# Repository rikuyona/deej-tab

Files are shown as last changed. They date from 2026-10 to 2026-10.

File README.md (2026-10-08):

# deej-tab

物理スライダーで、Windows / Mac のアプリごとの音量と **Chrome のタブごとの音量** を操作する自作ミキサーです。
[deej](https://github.com/omriharel/deej) を元に、PC アプリ・Chrome 拡張機能・LED 付きファームウェア・3D プリント用ケース（[MakerWorld](https://makerworld.com/models/3382344)）までまとめてあります。

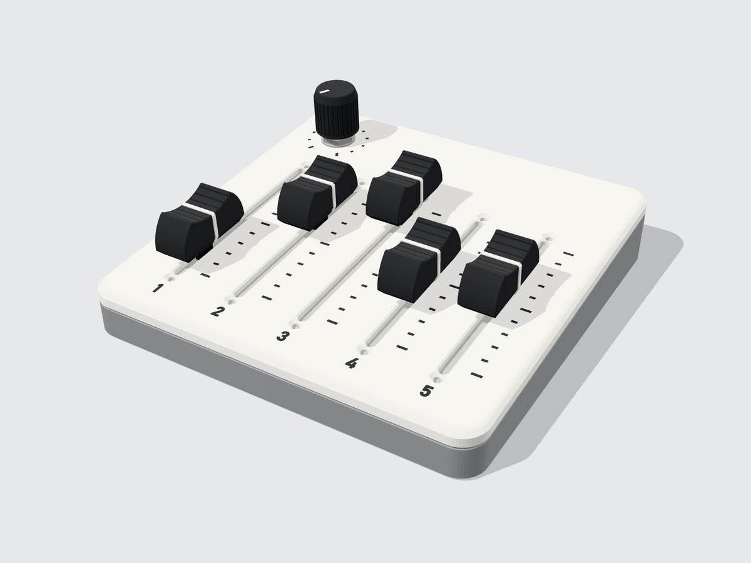
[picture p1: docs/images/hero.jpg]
deej-tab の完成イメージ

<p align="center"><sub>完成イメージ（3D レンダリング）。スライダー 5 本・ノブ 1 つ、外形 126×126mm</sub></p>

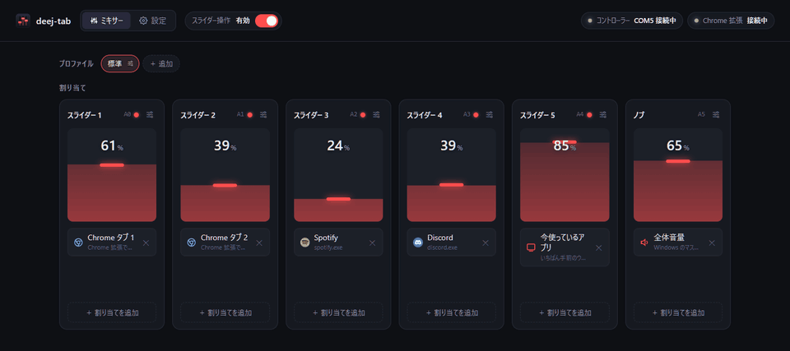
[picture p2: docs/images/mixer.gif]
設定画面：スライダーを動かすと、割り当てた音量がリアルタイムに変わる


- [できること](#できること) / [必要なもの](#必要なもの) / [セットアップ](#セットアップ) / [使い方](#使い方) / [Mac 版について](#mac-版について) / [仕組み](#仕組み) / [開発](#開発)

## できること

- スライダー 5 本＋ノブ 1 つに、全体音量・マイク・アプリ（Discord・Spotify など）・**Chrome のタブ**・今使っているアプリ・ゲーム・OBS の音声ソースを割り当てる
- Chrome で開いた配信や動画を、タブごとに別のスライダーで調整（Alt+Shift+A でタブを割り当て）
- 日本語・英語の画面（English UI）
- 設定画面で割り当て・スライダーごとの最大音量（100% 超えも可。タブ・OBS のみ）・音量の変わり方を変更
- プロファイル（割り当て一式）の切り替え。アプリが前に来たら自動で切り替えも可
- 一時停止（ショートカットも可）。止めるとアプリの音量を元に戻す（全体の音量はそのまま）
- スライダーの LED で状態や音の大きさを表示。光り方は設定画面で選べる
- config.yaml は deej と互換

## 必要なもの

### PC

- Windows 10 / 11、または macOS 14.2 以降の Apple シリコン（M1 以降）の Mac（Mac は [Mac 版について](#mac-版について) を参照）
- Google Chrome 116 以降（タブの音量を操作する場合）

### 部品

| 部品 | 例 | 数 |
|---|---|---|
| マイコン | Arduino Nano 互換ボード（USB Type-C 版。ケースは Mini-USB の Nano には合いません） | 1 |
| スライダー | Bourns PTL60-15R0-103B2（60mm・10kΩ B カーブ・赤 LED 付き） | 5 |
| 回転ボリューム | 16mm 型 10kΩ B カーブ（SH16K4B103L20KCCI など。6mm ローレット軸 18 山・軸長 20mm・M7 取付ネジ・回り止め付き） | 1 |
| ノブ | 3D プリント（[MakerWorld](https://makerworld.com/models/3382344) のデータ）または市販の 6mm 軸用（ABS-28 など） | 1 |
| LED 用抵抗 | 180Ω〜1kΩ（1/4W・1/6W など。例：330Ω） | 5 |
| M2 皿ネジ | M2×4 程度（ケースにスライダーを固定。1 本につき 2 本） | 10 |

LED 用抵抗：スライダーの赤色 LED はデータシートで順方向電流 20mA・順方向電圧 1.8V（標準）と規定されているので、5V で 20mA 以下にするには (5V − 1.8V) ÷ 20mA ≒ 160Ω 以上が必要です。値が小さいほど明るくなります（330Ω で約 10mA）。

LED なしのスライダーでも動きます（LED の機能が使えないだけです）。

### 配線

配線図

同じ名前の札どうしをつなぎます。5V と GND は全部の部品で共通なので、まとめて Nano の 5V・GND へつなぎます。

| 部品 | 端子 | つなぐ先 |
|---|---|---|
| スライダー 1〜5 | 1 | GND |
| | 3 | 5V |
| | 2（ワイパー） | A0〜A4 |
| | B（LED＋） | 抵抗 → D3 / D5 / D6 / D9 / D10 |
| | E（LED−） | GND |
| | L | つながない |
| 回転ボリューム | 両端 | 5V / GND |
| | 中央 | A5 |

D0 / D1 は USB シリアルに使うので空けておきます。

**基板版**：スライダー 5 本とノブを 1 枚の基板に載せ、Nano とはケーブル 3 本でつなぐ版も用意しています。配線が楽になります。基板を発注・組み立てて、6ch の値と LED が動くことを確かめてあります。ガーバーは [Releases](../../releases) の `pcb-v0.1.0`、部品・組み立て・注文のしかたは [pcb/README.md](pcb/README.md) にあります。

## セットアップ

[Releases](../../releases) から最新版の zip をダウンロードします。

### 1. ファームウェアを書き込む

1. `deej-tab-firmware-x.y.z.zip` を展開する
2. [Arduino IDE](https://www.arduino.cc/en/software) で `firmware/deej-6ch-led/deej-6ch-led.ino` を開く
3. ボード「Arduino Nano」、ポートを選んで書き込む
   - 互換品で失敗する場合は、プロセッサを「ATmega328P (Old Bootloader)」にする
   - ポートが出ない場合は CH340 のドライバを入れる
   - deej-tab が起動中だと書き込めません（トレイから終了してから）

### 2. PC アプリを入れる

1. `deej-tab-x.y.z-windows.zip` を展開し、好きな場所に置く（設定ファイルとログは exe の隣に作られます）
2. `deej-tab.exe` を起動する
   - 署名していないため「Windows によって PC が保護されました」と出ることがあります。「詳細情報」→「実行」で起動できます
3. タスクトレイのアイコンをクリックすると設定画面が開きます。「設定」→「コントローラー」でマイコンの COM ポートを選びます

Mac の場合は [Mac 版について](#mac-版について) を見てください。

### 3. Chrome 拡張機能を入れる

1. `deej-tab-extension-x.y.z.zip` を展開する（展開したフォルダは消さずに残しておく）
2. Chrome で `chrome://extensions` を開き、右上の「デベロッパー モード」をオンにする
3. 「パッケージ化されていない拡張機能を読み込む」で、展開した `deej-tab-extension` フォルダを選ぶ

更新するときは、新しい版でフォルダの中身を置き換えて、`chrome://extensions` の「更新」ボタン（↻）を押します。

### 4. ケースを印刷する（任意）

ケース・ツマミの 3D データは MakerWorld で配布しています。印刷設定と組み立て方もそちらにあります。

| 分解図 | スライダーのツマミ | 上から |
|---|---|---|
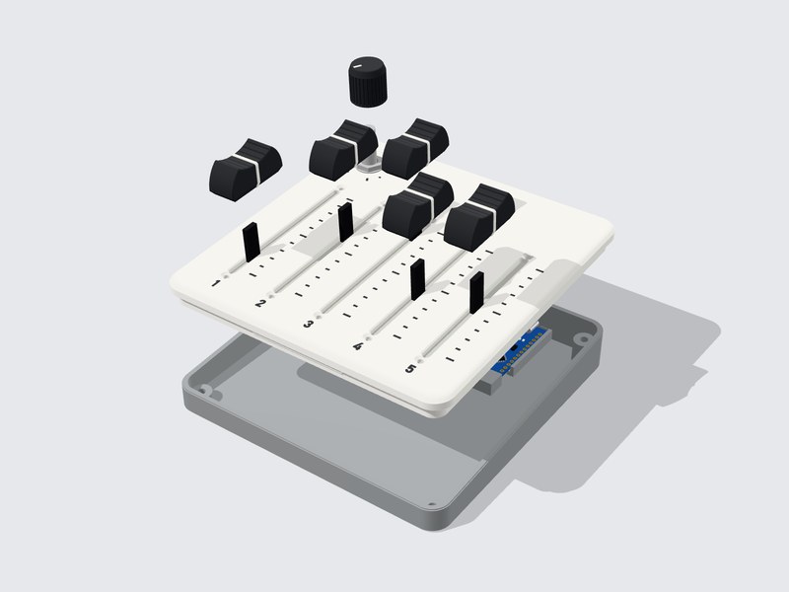
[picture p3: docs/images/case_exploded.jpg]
分解図
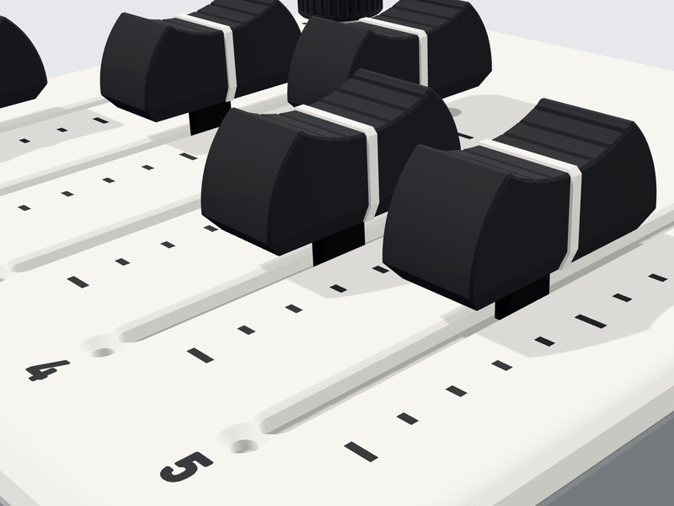
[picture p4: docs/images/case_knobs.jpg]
スライダーのツマミ
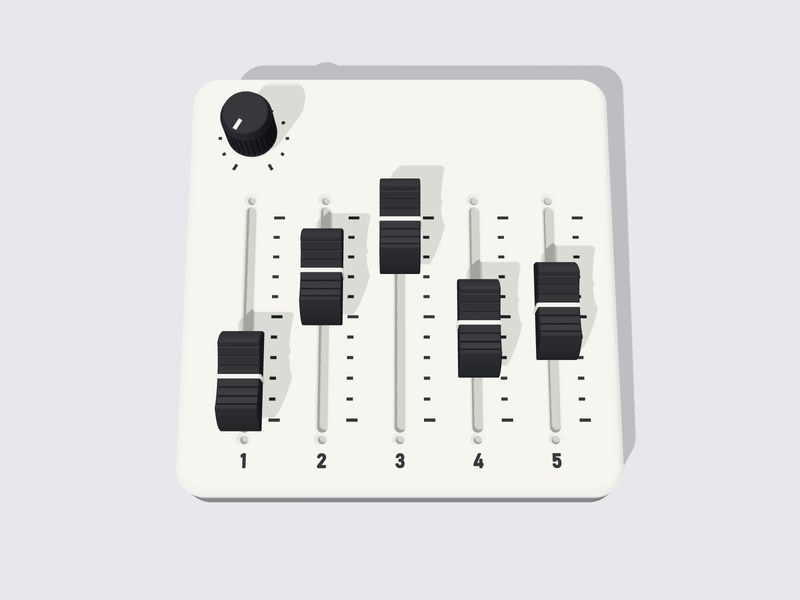
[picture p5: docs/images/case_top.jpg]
上から
|  |  |  |
| 天板・底ケース・Arduino Nano 固定クリップの 3 部品＋ツマミ | 黒い外殻と白い芯の 2 色。LED の光で白い線が光ります | 目盛りと番号は彫り。塗料を流し込んで色を付けます |

**MakerWorld：** [deej-tab Volume Mixer (5 faders + knob, LED)](https://makerworld.com/models/3382344)

寸法を変えたいときは `case/case.py` の先頭の設定を書き換えて作り直せます（[開発ガイド](docs/dev/README.md#ケースを作る)）。

## 使い方

deej-tab はタスクトレイに常駐します。アイコンをクリックすると設定画面が開きます。右クリックのメニューからは、一時停止・プロファイルの切り替え・自動起動のオン／オフ・終了ができます。

### ミキサー：スライダーに割り当てる

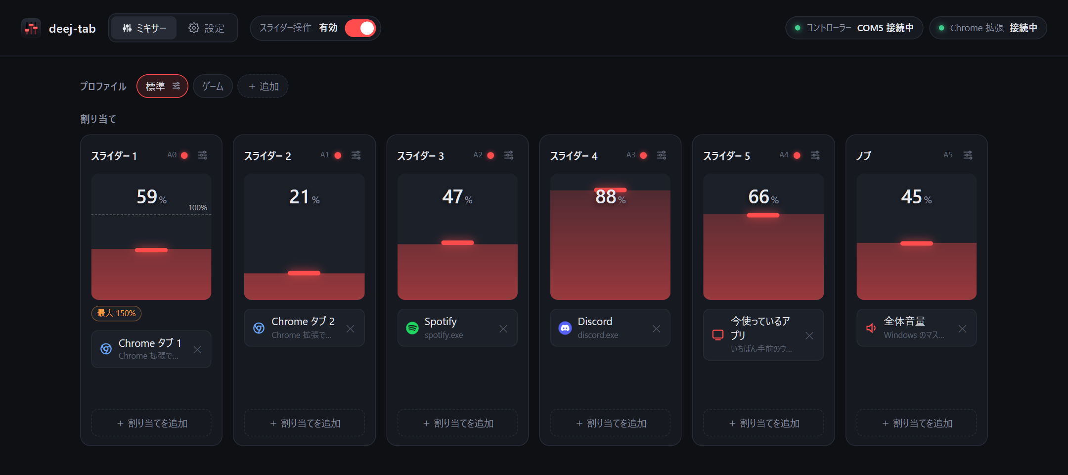
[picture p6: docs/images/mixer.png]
ミキサー


スライダー 1〜5 とノブのそれぞれに、操作したい音量を割り当てます。各スライダーの「＋ 割り当てを追加」から選び、1 本に複数を割り当てることもできます。メーターの塗りが今の音量、赤いつまみがスライダーの位置です。

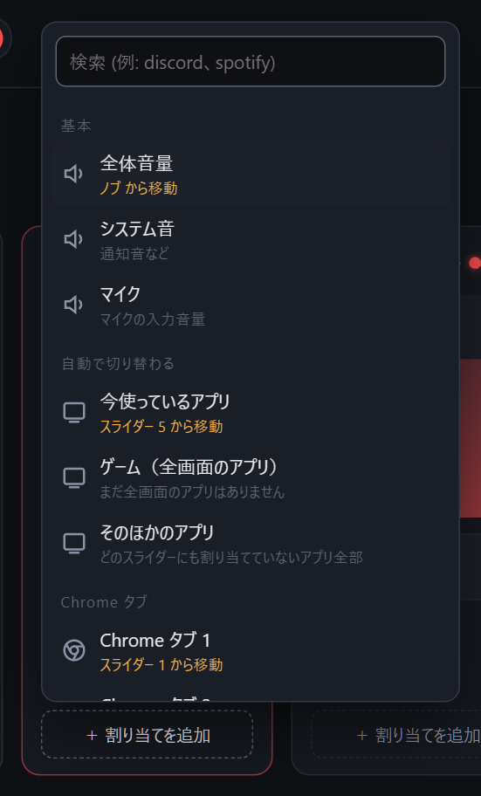
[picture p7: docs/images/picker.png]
割り当ての追加


選べるもの：

| 種類 | 内容 |
|---|---|
| 全体音量・システム音・マイク | Windows の音量 |
| 今使っているアプリ | いちばん手前のウィンドウのアプリ（ゲーム中ならゲーム） |
| ゲーム（全画面のアプリ） | 最後に全画面だったアプリ。ほかのウィンドウが前に来ても操作し続けます |
| そのほかのアプリ | どのスライダーにも割り当てていないアプリ全部 |
| Chrome タブ 1〜6 | 拡張機能で番号を付けたタブ（[下](#chrome-のタブの音量を操作する)） |
| アプリ | 音を出しているアプリ・起動中のアプリ・インストール済みのアプリから選べます。検索もできます |
| OBS の音声ソース | OBS 連携をオンにすると出ます |

同じ割り当て先は 1 本のスライダーにしか置けません（ほかのスライダーにあれば移動します）。

<br clear="right">

### スライダーごとの設定

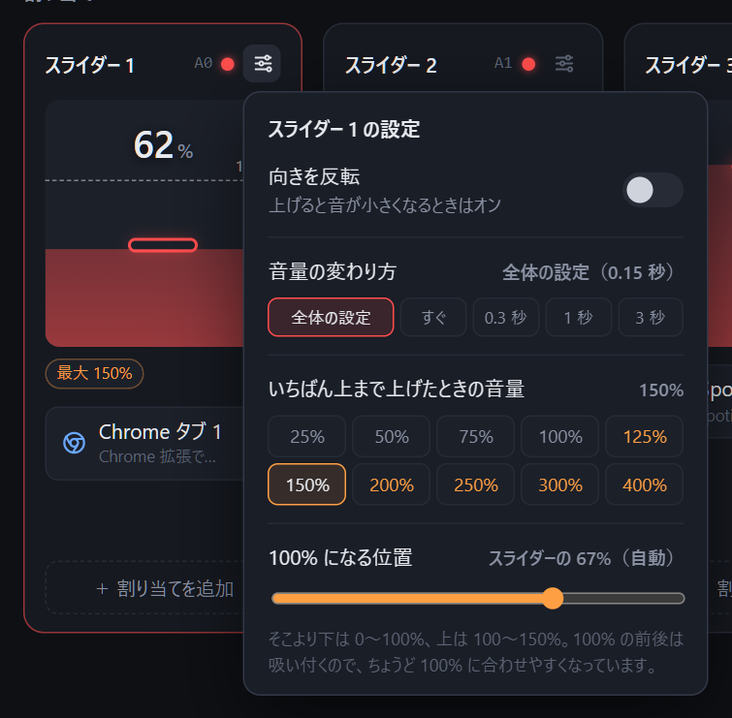
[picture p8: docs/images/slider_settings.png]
スライダーごとの設定


各スライダーの右上のアイコンから、そのスライダーだけの設定を変えられます。

- **向きを反転**：上げると音が小さくなるときに
- **音量の変わり方**：スライダーを速く動かしたとき、音量がどのくらいかけて追いつくか
- **いちばん上まで上げたときの音量**：25〜400%。100% を超える分は Chrome のタブと OBS だけに効きます（Windows の音量は 100% が上限）
- **100% になる位置**：スライダーのどこで 100% になるか

<br clear="right">

### Chrome のタブの音量を操作する

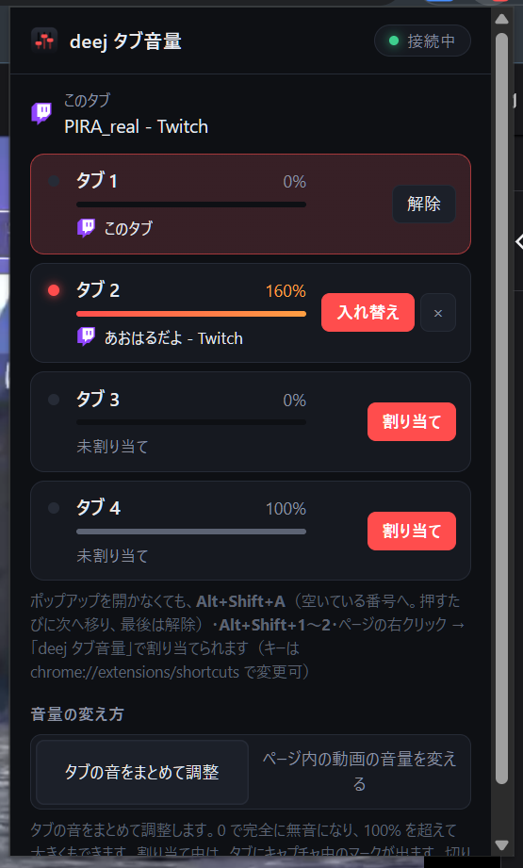
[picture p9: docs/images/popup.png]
拡張機能のポップアップ


1. 設定画面で、スライダーに「Chrome タブ 1」などを割り当てます
2. 音量を変えたいタブを開いて、**Alt+Shift+A** を押します。空いている番号に割り当てられ、ツールバーのアイコンに番号が出ます
   - もう一度押すと次の番号へ移り、最後は解除されます
   - **Alt+Shift+1・2** で番号を指定、ページの右クリック →「deej タブ音量」からも割り当て・解除できます（キーは `chrome://extensions/shortcuts` で変更できます）
3. 拡張機能のアイコン（**Alt+Shift+D**）を押すと、割り当ての一覧と今の音量が見られます。ほかのタブに割り当て済みの番号は、ここから入れ替えたり解除したりできます
4. ポップアップの「音が鳴ったタブを自動で割り当てる」をオンにすると、動画などの音が鳴り始めたタブが空いている番号に自動で割り当てられます（ポップアップでは番号の横に「自動」と出ます）。自動で割り当てたタブは「ページ内の動画の音量を変える」方式で調整します

ポップアップでは、番号ごとの今の音量（100% を超えるとオレンジ）と、割り当てたタブが見られます。

<br clear="right">

タブの音量は「Chrome のアプリ音量 × 全体音量」に対する割合です。音量の変え方は 2 種類あり、ポップアップで切り替えられます。

| 方式 | 内容 |
|---|---|
| タブの音をまとめて調整（初期設定） | タブの音声をキャプチャして音量をかけます。0 でしっかり無音になり、100% を超える音量にもできます |
| ページ内の動画の音量を変える | ページの動画・音声の音量を直接変えます。サイトによっては 0 でもかすかに聞こえます |

### プロファイル

割り当て一式に名前を付けて保存し、切り替えられます（ミキサーの上の「プロファイル」）。プロファイルごとに次のことができます。

- **自動で切り替え**：指定したアプリが前に来たら、そのプロファイルに切り替えます。アプリを終了すると元に戻ります
- **切り替えのショートカット**：キーを押して切り替えます

切り替えた直後は、スライダーが今の音量の位置を通るまで音量を変えません（音量が飛ばないように。設定でオフにできます）。

### 一時停止

設定画面の上の「スライダー操作」スイッチ、タスクトレイのメニュー、ショートカットで一時停止できます。一時停止中はスライダーを動かしても音量が変わりません。止めたときに、アプリ・マイク・OBS の音量を deej-tab が変える前に戻すこともできます（全体の音量は急に大きくならないよう、止めた時のまま）。

### 設定

設定画面の「設定」ページでは、次のものを変えられます。

- **言語**：自動（Windows の表示言語に合わせる）／日本語／English。タスクトレイのメニューと Chrome 拡張機能のポップアップ・右クリックメニューも切り替わります
- **コントローラー**：つなぐ COM ポート、全スライダーの向き、揺れの抑え、LED で知らせること、自動起動
- **LED の光り方**：操作していないとき・起動したとき・操作したときの光り方と明るさ。プレビューで確かめながら選べ、コントローラーに保存されるので PC から外しても同じ光り方になります
- **動作**：音量の変わり方、一時停止したら元に戻す、プロファイル切り替え時に音量を飛ばさない、一時停止のショートカット
- **OBS 連携**：obs-websocket で OBS の音声ソースを操作

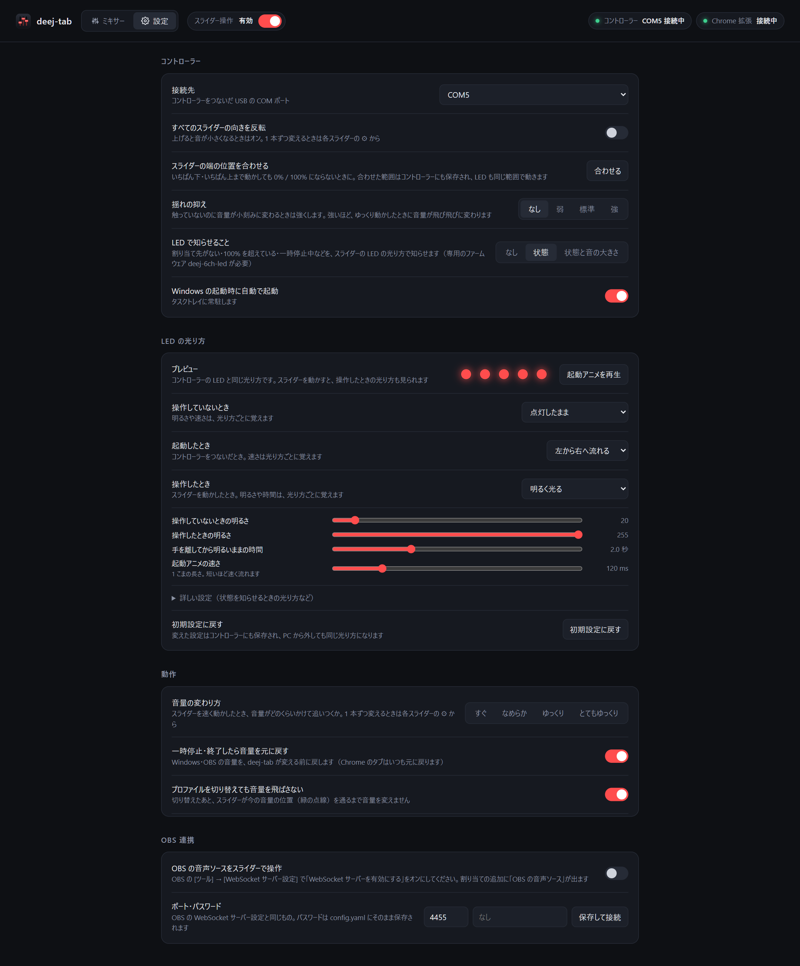
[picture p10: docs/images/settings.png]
設定ページ


#### スライダーの端の位置を合わせる

いちばん下・いちばん上まで動かしても 0% / 100% にならないときは、「コントローラー」→「スライダーの端の位置を合わせる」で各スライダーを端まで動かします。

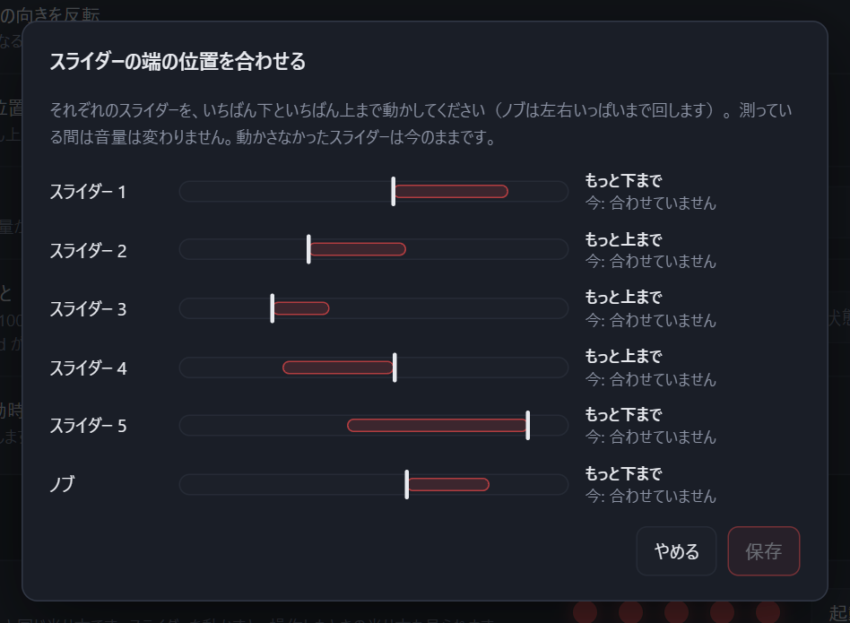
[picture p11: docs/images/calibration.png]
スライダーの端の位置を合わせる


設定は `deej-tab.exe` の隣の `config.yaml` に保存されます。手で書き換えても、保存すると自動で読み直します（形式は deej と互換）。

## Mac 版について

Apple シリコン（M1 以降）の Mac 用です。Intel の Mac では動きません。

### 入れ方

1. `deej-tab-x.y.z-mac.zip` を展開し、`deej-tab.app` を「アプリケーション」フォルダに入れる
2. 初回は右クリック →「開く」で起動する（Apple の署名をしていないため、ダブルクリックだと開けません）
3. コントローラーを USB でつなぐ。ふつうは自動で見つかります。見つからなければメニューバーのアイコンから設定画面を開き、「設定」→「コントローラー」で `/dev/cu.usbserial-…` を選ぶ（CH340 のドライバは macOS に入っています）
4. アプリごとの音量を初めて変えたときに「システムオーディオの録音」の許可を求められるので、許可する
   （システム設定 → プライバシーとセキュリティ → 画面とシステムオーディオの録音。音を受け取って音量をかけ直すだけで、録音・保存はしません）
   - 許可するまでの間、アプリの音は消えたままになります
   - 新しい版に入れ替えても許可は残ります

設定ファイルとログは `~/Library/Application Support/deej-tab/` に作られます。

### Windows 版との違い

- アプリは `.app` の名前で割り当てます（例：`discord.app`、`google chrome.app`）
- アプリごとの音量は macOS の Process Tap で、アプリの音を受け取って音量をかけ直して出力します。100% のアプリは何もしません
  - 音量を下げているアプリは、アプリ側で別の出力先を選んでいても Mac の出力先（システム設定のサウンド）から出ます
  - ごくわずかに音が遅れます（数十ミリ秒）
- 「システム音」には割り当てられません（Mac に通知音だけの音量がないため）
- LED を音に合わせるとき、マイクの音の大きさは表示しません（マイクの許可が必要になるため）
- ショートカットの Win は Command（⌘）、Alt は Option（⌥）です
- もう一度 `deej-tab.app` を開いても設定画面は出ません。メニューバーのアイコンから開いてください

## 仕組み

```
Nano ──USB シリアル──▶ deej-tab.exe ──Windows の音量 API──▶ アプリの音量
                       (Mac: deej-tab.app ──補助プログラム (Core Audio の Process Tap)──▶ アプリの音量)
 (スライダーの値)          │  ▲
                          │  └─ 設定画面 (http://127.0.0.1:8765/)
                          └─WebSocket──▶ Chrome 拡張機能 ──▶ タブの音量
```

拡張機能はタブの音声をキャプチャしてゲインをかけます。通信は PC の中（127.0.0.1）だけで、外部には何も送りません。

## 開発

ソースから動かす・exe や Mac 版を作る・ファームウェアを書き込む手順と、設計の資料は [開発ガイド](docs/dev/README.md) にまとめています。

## ライセンス

MIT License（[LICENSE](LICENSE)）。ファームウェアと config.yaml の形式は [deej](https://github.com/omriharel/deej)（MIT License, © Omri Harel）を元にしています。

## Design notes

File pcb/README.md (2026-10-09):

# スライダー基板（基板版）

スライダー 5 本とノブを 1 枚の基板に載せ、Nano とはケーブル 3 本（JST ZH の電源 3 ピン・LED 6 ピン・信号 6 ピン）でつなぐ版です。
配線版（スライダーごとに線を引き回す）の改良版で、Nano・USB-C の位置とファームウェアはそのまま使えます。
部品はすべてスルーホールで、手でハンダ付けします（JLCPCB には基板だけを頼む）。

> **実物で確認済みです（2026-10-08）。** 発注した基板を組み立てて、スライダー 5 本・ノブの値と LED 5 個が動くこと、ノブのボリューム（JH16K6）の端子が長穴に入ること、天板・基板・部品が合うことを確かめました。ガーバーは Releases の `pcb-v0.1.0` にもあります。

- 基板：`deej-tab-sliders.kicad_pcb`（KiCad 10 で開ける）
- 作り直し：`"%LOCALAPPDATA%\Programs\KiCad\10.0\bin\python.exe" make_pcb.py`
  - 部品の配置と信号の割り当てはスクリプトで決め、線は自動配線（Freerouting 2.4.1）に引かせる（30 秒ほど）。GND は自動配線から外し、表裏のベタでつなぐ
  - 要るもの（`%LOCALAPPDATA%\deej-tab\tools`）：`freerouting-2.4.1.jar` と、Java 25 の zip 版（Eclipse Temurin JRE 25 を展開した `jdk-25...-jre`）。インストールは不要
  - `out/deej-tab-sliders-gerber.zip`：JLCPCB に出すガーバー一式
  - `out/deej-tab-sliders-bom.csv`：買う部品の一覧
  - `out/drc.txt`：KiCad の DRC の結果（エラー 0。残りは自作の部品形状がライブラリにない旨の警告だけ）
  - `out/deej-tab-sliders-top.svg` / `-bottom.svg`：表・裏の図
  - `outline.json`：基板の外形・コネクターと部品の位置（`case.py --pcb` が読む）
- ケース：`case\.venv\Scripts\python case\case.py --pcb` → `case/out/pcb/`
  - 配線版の底ケースを持っていれば、刷り直さずに使える。基板版の天板は 1.8mm 薄いので、四隅の柱に `spacer.stl`（厚さ 1.8mm の輪 4 個）を載せる。四隅を M3 で締めるなら M3×10

## 基板の中身

| 部品 | 型番 | 数 | 置き場所 |
|---|---|---|---|
| スライダー | Bourns PTL60-15R0-103B2（今と同じ） | 5 | 表（ハンダは裏） |
| ノブのボリューム | **JH16K6B103L20KC-H13**（秋月 117390。今の SH16K4 と同じシリーズの基板用、10kΩB） | 1 | 表（パネルにナットで留める） |
| LED の抵抗 | カーボン抵抗 1/4W **150Ω**（足の間隔 10.16mm で寝かせる） | 5 | 裏（ハンダは表）。スライダーのすき間 |
| ノイズ対策 | 積層セラミックコンデンサー 0.1µF 50V **RD15F104Z1HL2L**（秋月 104065、10 個入り）各摺動子と GND の間 | 6 | 裏（ハンダは表） |
| 5V | 積層セラミックコンデンサー 10µF 25V **THD30E-1E106Z**（秋月 100464、足の間隔 5mm） | 1 | 裏（ハンダは表） |
| Nano へのコネクター | JST ZH 横向き **S3B-ZR-3.4**（JP）と **S6B-ZR-3.4**（JL・JA）（1.5mm、秋月） | 1＋2 | 裏（ハンダは表） |

- **LED の抵抗 150Ω**：赤 LED（Vf 1.8V、データシートの条件 20mA）に約 19mA。配線版の 330Ω（約 8.5mA）の約 2.2 倍の明るさ。5 個で約 95mA で、Nano（1 ピン 20mA 推奨）の範囲。これより下げると LED の 20mA を超える
- 基板の表はスライダー本体と天板（すき間 0.5mm）でふさがるので、抵抗・コンデンサー・コネクターの本体は裏に置き、表に出るハンダは天板の裏を 3mm 彫って逃がしている
- 基板：2 層・1.6mm・外形 100×100mm 以内（JLCPCB の最安枠）。Nano の真上は切り欠いてあり、Nano にハンダ付けする線の邪魔をしない
- ボリュームは今と同じくナットでパネルに留める（パネルの穴・回り止め・印刷のノブ・目盛りは配線版と同じ）。本体は取付面から 9.3mm とスライダー（7.0mm）より深いので、基板の左奥を切り欠いて本体を通す。端子は軸と平行に後ろへ伸びているので、その途中（幅約 2.9mm の板の所）を基板の**長穴**（3.3×0.9mm）でハンダ付けする
- 配線：自動配線（信号は主に裏、表はほぼベタ GND）。表裏ともベタ GND
- スライダーは今と同じ位置（22mm 間隔、ケースの X = 19 / 41 / 63 / 85 / 107）。端子は 4 本の列を手前にして上から見て左から 2・1・L・E（実物で確認済み）。ノブも同じ位置（19, 106）

## ケーブル（JP・JL・JA → Nano）

電源・LED・信号で 3 本に分けている。秋月のコネクター付コード（ZH 相当、片側ハンダメッキ）をそのまま挿し、ハンダメッキの側を Nano に付ける。1 番は四角いパッド。

- **JL（LED）と JA（信号）は Nano のすぐ左に縦に並び、口は Nano 向き（右）**。端子の並びは Nano の端子と同じ前後の順なので、コードはまっすぐ右へ出して、そのまま隣の Nano の端子に付けられる。1 番は奥の端
- **JP（電源）はボリュームの近く、口は手前**。コードは基板の下を手前へ出して、Nano の手前の端の 5V・GND へ

| コネクター | コード | 番号 | 信号 | Nano の端子 |
|---|---|---|---|---|
| JP 電源（3 ピン） | 3P 黒白赤（秋月 118272） | 1 | GND | GND（D 側） |
| | | 2 | +5V | 5V（A 側） |
| | | 3 | GND（予備） | 付けなくてよい |
| JL LED（6 ピン） | 6P(H) 白赤黒青黄緑（秋月 105719） | 1（奥） | D10 | D10（スライダー 5 の LED） |
| | | 2 | D9 | D9（スライダー 4） |
| | | 3 | D6 | D6（スライダー 3） |
| | | 4 | D5 | D5（スライダー 2） |
| | | 5 | D3 | D3（スライダー 1） |
| | | 6（手前） | 空き | 付けない |
| JA 信号（6 ピン） | 6P(H) 白赤黒青黄緑（秋月 105719） | 1（奥） | A0 | A0（スライダー 1） |
| | | 2 | A1 | A1（スライダー 2） |
| | | 3 | A2 | A2（スライダー 3） |
| | | 4 | A3 | A3（スライダー 4） |
| | | 5 | A4 | A4（スライダー 5） |
| | | 6（手前） | A5 | A5（ノブ） |

- JA のコードは Nano の A 側（A0 が奥、A5 が手前）、JL のコードは D 側の D10・D9・D6・D5・D3 に、それぞれ真横へ付ける
- **コードの色と番号の対応は、Nano に付ける前に確かめる**（基板に挿して、テスターで基板の端子とコードの先の導通を見る）。コネクターは向きが決まっているので挿し間違いはない。1 番の位置はデータシートの図から読んだもの
- コードは 20cm あるので、Nano までの長さに切ってから付ける（JA・JL は数 cm、JP は 10cm ほど）
- ファームウェア・アプリは今のまま（ピンの割り当ては配線版と同じ）

## 組み立て

1. 抵抗・コンデンサー・JP・JL・JA を**裏から挿して表でハンダ付け**し、表に出た足は短く切る
   - コンデンサーは基板に押し付けて付ける（裏の部品と底ケースの床のすき間はいちばん狭い所で約 2mm）
   - 抵抗は寝かせて付ける
2. 天板に、スライダーを表から M2 皿ネジ（**M2×4、10 本**）で、ボリュームをナットで留める。基板版は本体の下に基板があるので、配線版の爪はない
3. 基板を裏からかぶせる（スライダーの端子とボリュームの 3 本の端子が穴に入る）
4. 裏からスライダーとボリュームをハンダ付けする（パネルに合った位置で固まる）。ボリュームの端子は基板から約 5mm 出るので、ハンダのあと短く切る
5. コードを JP・JL・JA に挿し、Nano へ。天板を底ケースに閉じる

## JH16K6 の端子

- データシートの図から、端子は軸の中心から 13mm・5mm 間隔、取付面の 3.4〜13.4mm 後ろまで伸びる板（幅約 2.9mm・厚さ約 0.4mm、先の 4mm だけ細い）と読んだ。基板はその幅の広い所（取付面の 7.0〜8.6mm 後ろ）を通る。実物の端子が長穴（3.3×0.9mm、`make_pcb.py` の `POT_SLOT`）に入ることを確認済み

## JLCPCB への注文

1. `out/deej-tab-sliders-gerber.zip` をアップロード（2 層・1.6mm・その他は初期設定のまま）
2. 部品実装（PCB Assembly）は使わない（部品はすべて手でハンダ付け）

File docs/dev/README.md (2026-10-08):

# 開発ガイド

deej-tab をソースから動かす・作る・配布するための資料です。使い方は [README](../../README.md) を見てください。

## 資料

| 資料 | 内容 |
|---|---|
| [hardware.md](hardware.md) | 部品・配線・ファームウェア（通信の形式、LED、ID、端の位置の保存） |
| [app.md](app.md) | PC アプリの構成と機能の設計（音量の計算、一時停止、プロファイル、LED、OBS など） |
| [extension.md](extension.md) | Chrome 拡張機能（タブの音量の変え方、割り当て、通信） |
| [mac.md](mac.md) | Mac 版（補助プログラム、Process Tap、Windows 版との違い） |
| [case.md](case.md) | 3D プリントのケースとツマミ（`case/case.py`） |
| [pcb.md](pcb.md) | 基板版（スライダーを 1 枚の基板に載せる） |
| [wording.md](wording.md) | 画面に出す文言のルール |
| [status.md](status.md) | 版の履歴・未確認のこと |

## 全体の仕組み

```
Nano ──USB シリアル──▶ deej-tab ──OS の音量 API──▶ アプリの音量
 (値 0〜1023 × 6)        │  ▲   (Mac: 補助プログラム → Core Audio の Process Tap)
 ◀── LED の指示 ─────────┘  │
                            ├─ 設定画面   http://127.0.0.1:8765/  (WebSocket /ui)
                            ├─ 拡張機能   ws://127.0.0.1:8765/    → タブの音量
                            └─ OBS        obs-websocket v5        → 音声ソースの音量
```

通信は PC の中（127.0.0.1）だけで、外部には何も送りません。

## フォルダ

| フォルダ | 中身 |
|---|---|
| `app/` | PC アプリ。`deej_tab.py` が本体、`ui.html` が設定画面、`leds.py` が LED の計算、`winsys.py` / `macsys.py` が OS ごとの部品、`appcatalog.py` がアプリ一覧、`obs.py` が OBS 連携 |
| `app/mac/` | Mac の補助プログラム（Swift） |
| `app/tests/` | テスト（unittest） |
| `extension/` | Chrome 拡張機能（Manifest V3） |
| `firmware/deej-6ch-led/` | Arduino Nano 用ファームウェア |
| `case/` | ケース・ツマミの 3D データを作るスクリプト |
| `pcb/` | 基板版の KiCad データと、それを作るスクリプト（[pcb/README.md](../../pcb/README.md)） |
| `tools/` | 仮スライダー・拡張機能のアイコン作り・配布用 zip 作り |
| `docs/` | README の画像と、この開発資料 |

## Windows で動かす

Python 3 が必要です（3.14 で確認）。

```bat
cd app
start.bat
```

初回は `.venv` を作って必要なパッケージを入れ、トレイに常駐します。ログを画面で見たいときは `debug.bat`（`--no-tray`）。ログは `app/deej-tab.log` にも出ます。

| 作業 | コマンド（`app` フォルダで） |
|---|---|
| テスト | `.venv\Scripts\python -m unittest discover -s tests -v` |
| exe を作る | `.venv\Scripts\python build.py` |
| 配布用 zip を作る | `.venv\Scripts\python ..\tools\release.py --build`（`release/` にできる） |

- `.venv` は別の場所からコピーすると壊れます（pip が入っていない）。壊れたら `py -3 -m venv --clear .venv` で作り直します
- `build.py` は PyInstaller の onefile で `app/deej-tab.exe` を作ります。起動中の exe は置き換えられないので、トレイから終了してから実行します

### コントローラーなしで試す

`tools/fake_sliders.bat` で 6 本の仮スライダーが開き、`socket://127.0.0.1:9000` に値を送ります。`config.yaml` の `com_port` をこの値にすると、deej-tab が仮スライダーにつながります。

- 全部 0 / 50 / 100%、揺れを混ぜる（揺れの抑えを試す）、送るのを止める（つなぎ直しを試す）、`--port` で別のポート
- クリックしても最前面のアプリが変わらない（「今使っているアプリ」を試せる）
- deej-tab から届いた LED の指示を `leds.LedSim` で再現して表示します

## Mac で動かす

Xcode のコマンドラインツール（`xcode-select --install`）と Python 3 が必要です（Homebrew の Python 3.12 で確認）。

```sh
cd app
python3 -m venv .venv-mac
.venv-mac/bin/pip install -r requirements-mac.txt
.venv-mac/bin/python build_mac.py --helper-only   # 補助プログラム (mac/deej-tab-helper.swift) を作る
.venv-mac/bin/python deej_tab.py --no-tray        # ログを見ながら動かす
.venv-mac/bin/python build_mac.py                 # deej-tab.app と release/deej-tab-x.y.z-mac.zip を作る
```

ターミナルから動かすと、システムオーディオの録音の許可はターミナルに対して求められます。エディタや Claude Code などターミナル以外から動かすと、許可のダイアログが出ないまま音量を変えたアプリの音が消えることがあります。その時は `build_mac.py` で作った `deej-tab.app` で試します。詳しくは [mac.md](mac.md)。

## ファームウェアを書き込む

Arduino IDE（ボード「Arduino Nano」）か arduino-cli で書き込みます。互換品は旧ブートローダーが多いので、失敗したらプロセッサを切り替えます。

```bat
cd firmware
arduino-cli upload -p COMx --fqbn arduino:avr:nano:cpu=atmega328old deej-6ch-led
```

deej-tab が起動中だと COM ポートが開けないので、先に終了します。

## ケースを作る

`case` フォルダで `pip install numpy trimesh manifold3d` を入れた venv を作り、`python case.py` を実行します。出力は `case/out/`（STL・部品を入れた状態を回して見られる `viewer.html`・断面図）。寸法はファイル先頭の設定で変えられます。詳しくは [case.md](case.md)。

## ブランチとリリース

- `main` が公開している版です。大きな変更はブランチで作り、PR でマージします
- 版の番号は、アプリが `app/deej_tab.py` の `VERSION`、拡張機能が `extension/manifest.json`、ファームウェアが `.ino` の `FW_VERSION` です。ファームウェアの zip はアプリの版の名前で作ります
- リリースの手順
  1. `VERSION` を上げ、テストを通す
  2. `tools/release.py --build` で Windows 版・拡張機能・ファームウェアの zip を `release/` に作る
  3. Mac で `build_mac.py` を実行して Mac 版の zip を作る
  4. main にコミットしてタグ `vX.Y.Z` を push し、GitHub の Releases に zip を載せる（ノートは日本語と英語の両方）
- 拡張機能だけを直した時は、タグを `extension-vX.Y.Z` にし、アプリ・Mac 版・ファームウェアは前の版の zip をそのまま一緒に載せる（Latest からすべて揃うように）
- 基板版のガーバーと部品の一覧は、タグ `pcb-vX.Y.Z` のプレリリースに載せる（Latest にしない。アプリ・拡張機能の Latest からすべて揃うように）。実物で確かめたらプレリリースを外す
- ケース・ツマミの STL は Releases ではなく [MakerWorld](https://makerworld.com/models/3382344) で配っています

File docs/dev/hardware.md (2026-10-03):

# ハードウェアとファームウェア

## 部品

| 部品 | 型番 | 数 |
|---|---|---|
| マイコン | Arduino Nano 互換（CH340C・USB Type-C） | 1 |
| スライダー | Bourns PTL60-15R0-103B2（60mm・10kΩ B カーブ・赤 LED 付き） | 5 |
| 回転ボリューム | SH16K4B103L20KCCI（16mm 型・10kΩ B カーブ・6mm ローレット軸 18 山） | 1 |
| ノブ | 3D プリント、または ABS-28 | 1 |
| LED 用抵抗 | 330Ω（180Ω〜1kΩ） | 5 |

- ボリュームはすべて B カーブ（直線）なので、値は位置に比例します（中央 ≒ 512）
- LED の抵抗：赤 LED は順方向電圧 1.8V・データシートの条件 20mA。5V で 20mA 以下にするには 160Ω 以上。330Ω で約 10mA

### PTL60 の端子

データシートの穴の図は上から見た図で、「3 は 1 と同じ線上、B は E と同じ線上」です。4 本の列を手前にして上から見ると、摺動子（2）が左端です（実物で確認済み）。

## 配線

| 部品 | 端子 | つなぐ先 |
|---|---|---|
| スライダー 1〜5 | 1 | GND |
| | 3 | 5V |
| | 2（摺動子） | A0〜A4 |
| | B（LED＋） | 抵抗 → D3 / D5 / D6 / D9 / D10 |
| | E（LED−） | GND |
| | L | つながない（ダミー端子） |
| 回転ボリューム | 両端 | 5V / GND |
| | 中央 | A5 |

- D0 / D1 は USB シリアルに使うので空けておきます
- LED のピンは PWM が使えるものから選んでいます

### Nano の端子の並び（USB 側 → 反対側）

| 側 | 並び |
|---|---|
| D 側（ケースの右端側） | D12 D11 **D10 D9** D8 D7 **D6 D5** D4 **D3** D2 **GND** RST RX0 TX1 |
| A 側（スライダー 4 側） | D13 3V3 REF **A0〜A5** A6 A7 **5V** RST GND VIN |

- A 側は A0〜A4 の線をスライダーへまっすぐ出せます
- GND は D 側の 4 本目（端から約 11.7mm）を使います。A 側の GND は押さえ（[case.md](case.md)）の縁から約 1.1mm しかありません
- 押さえがかぶさるのは 1 本目（TX1・VIN）と ICSP（2×3）だけで、どれも使いません

## ファームウェア（`firmware/deej-6ch-led`）

公式 deej の `deej-5-sliders-vanilla` を元にした 6 チャンネル版です。値の送り方は公式と同じなので、公式 deej からも使えます。

### 値の読み取り

- 1 回読み捨ててから 8 回平均します（`OVERSAMPLE`）。ピンを切り替えた直後は前のピンの電圧が残るためです
- 3 未満の変化は前の値のままにします（`HOLD`。0 と 1023 は必ず出す）。これで触っていない時の揺れが ±6 から 0 になりました
- 約 10ms ごとに `v0|v1|v2|v3|v4|v5`（生の値 0〜1023）を送ります。端の位置の補正はアプリ側で行います（deej 互換のため）

### PC とのやりとり

Nano → PC：

| 行 | 意味 |
|---|---|
| `512\|0\|1023\|…` | スライダーの値（6 本） |
| `@ID\|deej-6ch-led\|1.3\|1E5F90CC` | ファームウェアの名前・版・コントローラーの ID。起動時と `@I` を受けた時に送る。公式 deej は `@` の行を読み飛ばす |

PC → Nano：

| 行 | 意味 |
|---|---|
| `@L\|g\|m0\|…\|m4` | LED の状態。`N` 普通・`O` 消灯・`D` 暗く（割り当て先が動いていない）・`B` 明滅（100% 超え）・`P` 点滅（ピックアップ待ち）。`g=1` は一時停止中 |
| `@V\|l0\|…\|l4` | LED を音に合わせる時の音の大きさ（-48dB〜0dB を 0〜255、15 回/秒） |
| `@P\|DIM=20\|…` | LED の光り方の数値（1 行 60 文字まで）。変わった時と 5 秒ごと |
| `@C\|番号\|下端\|上端` | スライダーの端の位置。変わった時と 5 秒ごと |
| `@B` | 起動アニメを再生する |
| `@I` | ID を聞く |

- 3 秒何も来なければ、PC なしの光り方に戻ります
- 形が違う行・範囲外の値は捨てます（範囲外の数値は範囲に収める）

### LED

PC なしの光り方（PC からの指示がない時）：

- 普段は暗めに点灯し、操作したスライダーだけ明るくして戻す
- 0 まで下げたら消灯
- しばらく操作がないと減光（`SLEEP_MS`）
- 起動時に光が流れる

光り方は普段・起動・操作した時の 3 つを選べ、数値は `paramTable` の変数です（名前と範囲は `leds.PARAM_LIMITS` と同じ。テスト `test_firmware_matches` で確かめる）。計算はアプリの `leds.led_brightness()` と同じにしてあり、設定画面のプレビューと仮スライダーはこれを使います。

- 波紋（操作した LED から端まで広がる）は、割り当て先が動いていない（`D`）LED にも出します。`D` の LED を操作した時は `INACTIVE_TOUCH` から広げます（真ん中より隣が明るくならないように）
- 明るくする時は速く、暗くする時はゆっくり変えます。点滅・一時停止の明滅はそのまま出します

### EEPROM

| 番地 | 中身 |
|---|---|
| 0〜 | LED の光り方の数値（`paramTable` の順） |
| 200〜 | スライダーの端の位置（6 本分） |
| 240〜 | コントローラーの ID（目印＋32 ビット） |

- 受け取ってから 2 秒後に保存します（`EEPROM.put` なので同じ値なら書かない）。PC から外しても同じ光り方になります
- **数値を足す時は `paramTable` の最後に足します**（順番で保存しているため）

### コントローラーの ID

CH340 は USB のシリアル番号を持たないので、別の USB の口に差すと COM 番号が変わります。チップには書き込めないので、ファームウェアに ID を持たせました。

- 初めて起動した時に、アナログ入力の揺れと `micros()` から 32 ビットの ID を作って EEPROM に保存します（書き込み直しても消えない）
- アプリ側の探し方は [app.md](app.md#コントローラーをつなぐ)

### 容量

フラッシュ 46%・RAM 51%（arduino-cli 1.5.1・arduino:avr 1.8.8、旧ブートローダーの Nano）。

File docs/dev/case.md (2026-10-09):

# ケースとツマミ（`case/case.py`）

1 本のスクリプトでケース・ツマミ・試し刷り用の部品を作ります。寸法はファイル先頭の設定で変えられ、出力は `case/out/` です。部品とケースの干渉も確かめます。配布用の STL は [MakerWorld](https://makerworld.com/models/3382344) に載せています。基板版のケース（`case.py --pcb`）は [pcb.md](pcb.md) を見てください。

| 出力 | 中身 |
|---|---|
| `top_plate.stl` | 天板（一枚もの） |
| `bottom_case.stl` | 底ケース |
| `nano_clip.stl` | Nano の押さえ |
| `cap_core.stl` + `cap_shell.stl` | スライダーのツマミ（芯と外殻の 2 色） |
| `knob_body.stl` + `knob_line.stl` | ノブ（本体と指示線の 2 色） |
| `fit_test.stl`・`knob_fit_test.stl` | はめ合いの試し刷り |
| `pcb/spacer.stl`（`--pcb` だけ） | 配線版の底ケースに基板版の天板を載せる時の、四隅の柱のスペーサー 4 個 |
| `viewer.html` | 部品を入れた状態を回して見られるページ |
| `*_section.png`・`*_drawing.png` | 断面図・図面 |

## 前提

- プリンター：Bambu Lab A1 mini＋AMS（ベッド 180×180×180、多色刷り）
- フィラメント（Bambu PLA Matte、`PART_FILAMENT`）：天板＝アイボリーホワイト、底ケース＝アッシュグレー、ツマミの外殻・ノブ＝チャコール、ツマミの芯・ノブの指示線＝アイボリー
- 見た目：ミニマル・インダストリアル（キーボードの Lofree Flow に寄せた）。書体は Bahnschrift

## 外形と配置

- 外形 126×126、高さは手前 16.2mm・奥 23.5mm（傾き 3.3°）。パネル・底は 2.0mm。角の丸み R8、上の縁は 45° 面取りから丸みにつなぐ
  - 手前 13.4mm にしたかったが、スライダー（パネルの下 10.5mm＋配線 2.5mm）が入らないので、差 7.3mm を保って最低限まで上げた
- スライダー 5 本を 22mm 間隔（X = 19・41・63・85・107、中心 Y = 51）、ノブは左奥（19, 106）、Nano は X = 90（スライダー 4・5 の奥端の下）で USB-C を奥に出す
- Nano の位置は、端子の下の配線の余裕 2.5mm を取ったうえで、いちばんすき間が残る所を総当たりで選んだ（残り 0.5mm）
- 部品は実物寄りにモデル化しています（スライダーは本体 7mm＋両端の端子、Nano は基板・USB-C・表裏の部品・端子列の配線）。干渉チェックには端子の下の配線の余裕と、ツマミが動く範囲も含めます

### 寸法の出典

| 部品 | 寸法 |
|---|---|
| PTL60（Bourns） | 本体 75×9、取付面から下 7（±0.5）＋端子 3.5、M2 ネジ間隔 71、溝 67。レバーは取付面から 15 |
| レバー（実測） | 厚さ 2.0・幅 6.0、上から下まで同じ厚さ（データシートの先端の段は無い）。上から 5〜6mm に幅の両端が 0.5 くぼむ横溝。LED は上の 5×5 の中 |
| SH16K4（Supertech） | Φ17、奥行き 9.3、M7×0.75、軸は取付面から 20、回り止めは中心から 7.8、回転角 300° |
| ABS-28 | Φ15×15.7 |
| Nano（実測） | 基板 17.8×43.4×1.1（図面の 18×43.5×1.6 より薄い） |

## 天板（`top_plate.stl`）

厚さ 10.3mm の詰まった一枚板で、**表を上にして刷ります**。サポートは外側の帯の下（分割溝の所、幅約 2.2mm の張り出し）だけ「ビルドプレートのみ」。

- 厚さ ＝ パネル 2＋スライダー本体 7＋爪の返しのすき間 0.2＋返し 1.1。裏は平らでプレートに接します
- パネル上面から 5mm（`BAND`）の所に側面一周の分割溝（高さ 0.8・深さ 0.5）。ここで天板と底ケースが分かれ、合わせ目は溝に隠れます。溝より下は底ケースの壁の内側に入る差し込み（すき間 `FIT` 0.3）
- 裏のくぼみ（貫通）：スライダー本体 9.6×75.6（`POCKET_FIT` 0.3）、ボリューム Φ18＋端子の逃げ。M2 の皿ネジ穴も残します
- **スライダーの爪**（`SLIDER_CLAW`）：くぼみの長い壁を U 字に切り離した板（厚さ 1.2・幅 6）を、本体の中心から前後 ±22 に左右 2 つずつ。返しが本体の下に 0.6 掛かり、裏から押し込むと斜面で外へ逃げます。本体 7.2mm に掛かる位置（どうせ M2 でも留めるので、短い個体は気にしない）
- 目盛り（各スライダーの右に 11 本、0・50・100% は長い）・番号 1〜5・ノブの目盛り（300°）は**彫り**（深さ 0.4、`MARK_DEPTH`）。刷ったあとに塗料（水性アクリル・スミ入れ塗料・ポスカなど。ラッカー系は PLA を傷める）を流し込んで拭き取ります
  - 多色で刷る方法はどれもきれいに出なかった（彫って別の色で埋める形はスライサーが底に床を作らず色がインフィルに落ちた／表に盛る形は質が低かった）。パネル面を下にする案はプレートがテクスチャ付きなので不可
  - 線幅はどれも約 0.9mm（0.4 ノズルで 2 本ちょうど。目盛り `TICK`、文字は輪郭を 0.2 太らせる `TEXT_GROW`、高さ 3.8 `LABEL_H`）。0.8 の線や 0.6 の文字の画は汚くなった
  - 文字の塗り方は NonZero（フォント本来）。EvenOdd だと「4」の交差に穴が空いた
- 0.08mm の層で刷ると天面にインフィルの模様が透けます（ピローイング）。疎インフィル 100% か、上部シェル 1.0mm 以上にします

## 底ケース（`bottom_case.stl`）

底＋分割溝より下の側面、四隅の柱、Nano の台、USB-C の穴、スナップの溝。底を下にしてそのまま刷ります。底の下の縁は 1.2 面取り（浮いて見える）。

### 天板と底ケースの留め方

- **スナップフィット**（`SNAP`）：差し込みの各辺の中央（長さ 40）に台形の出っ張り（0.7 出る、先の平ら 0.4、両側 45°）、底ケースの壁の内側に溝（深さ 0.6、長さ 42）
  - はまった時に出っ張りの上の斜面が溝の上の斜面にぴったり触れる寸法にすると、ガタが出ません。溝の下側は 0.3・奥は 0.2 のすき間
  - 手前・奥の辺に置く形は、パネルの傾きで深さ 7.5 の所が前後に 0.43 ずれるので戻します（`snap_bars` の k）
- **四隅の柱**：底ケースから天板の裏の 0.2 下まで立てます（`BOSS_GAP`。締めた力が分割面にかかる）。足りなければ M3×8（なべ / キャップ）で、底の座ぐり（Φ6.4）から天板の裏へ締められます（かかり 4.9）。傾きの分は座ぐりの深さで吸収（`screw_seat_z`）

## Nano の押さえ（`nano_clip.stl`）

USB の抜き挿しで基板が奥を支点に傾き、手前が浮いたので足した部品です。原因は、台が奥 31mm だけで手前を支えるものがなかったことと、基板が実測で薄く（1.1mm）USB-C が穴の下の縁に当たって奥だけ持ち上がったことでした。

- 基板は台より 0.45 上（`nano_seat_z()`、USB-C が穴の中で上下に少し空く高さ）に、押さえと USB-C の穴で水平に固定します
- 形は **1 つの箱から「止めが入るくぼみ」と「基板の手前の端が入るすき間（高さ 1.15）」を削っただけ**。すき間の上が基板を押さえ、下が裏を受け、左右が角を挟みます。部品を足し合わせると細かいすき間や段ができたので、削る形にしました
- 基板の端から 4.6mm まで全幅で押さえます（ICSP と 1 本目の端子は使わないので押さえてよい）
- 底ケースの止め（板）の厚さは 1.75mm（`NANO_STOP_T`。1.6 で作ったら刷り上がりが細かった）
- 押さえのくぼみと止めのすき間は、前後・横とも片側 0.05（`NANO_CLIP` の最初の値）。0.2 では、止めの板が刷り上がりで約 0.2 薄く出るぶん遊んでスカスカだった。ゆるいと直せないが、きつければ削って合わせられるので、きつめにしている
- 手前の面を下に立てて刷ります。サポートなし
- 組み立て：押さえを基板の手前の端に差してから、一緒にケースへ下ろします（先に接着すると基板が入らない）
- 実物で組んで、はめ合いを確かめ済み

## スライダーのツマミ（`cap_core` + `cap_shell`）

秋月の CS-52 と同じ 2 色構成です。乳白の芯（レバーの穴と指示線の板）に黒い外殻（厚さ 1.2、前後 2 つ）をかぶせ、レバーの LED の光が芯を通って上面と両側面の白い線が光ります。

- 形：横から見て、下の帯（高さ 2.2）から両端が外へふくらむ円弧で細い山へ、上面は山から山への大きな凹んだ円弧（`cap_side_pts`・`CAP_BAND`・`CAP_HORN`）。手が触れる所は角があるほうがよいので、丸い形はやめた
- 上面に片側 3 本の V 溝（`CAP_NOTCH`）、白いラインは 0.35 盛り上げる（`CAP_LINE_RAISE`）。境目は 0.3 面取り（`CAP_EDGE`、白いラインの角だけ 0.6）
- 幅 11.5、長さ 28、山の高さ 13.4、谷はレバーの上 1.6。パネルの上 4.5mm に浮かせ、レバーに 8.5 差し込みます
- 穴は段なしの 2.0×6.0＋すき間 0.2（`CAP_FIT`）。両端にレバーの横溝へはまる丸い爪（`CAP_SNAP`、かかり 0.25）。穴の壁と一体で、押せば入り引けば抜けます
- 底面を下にして AMS の 2 色で刷ります。毎層色が替わるので、5 個まとめて刷ると交換回数を分け合えます
- マット PLA は光を通しにくいので、白いラインの光り方が弱ければ芯だけ透明系の PLA / PETG にします

## ノブ（`knob_body` + `knob_line`）

ABS-28 と外形（Φ15×15.7）・底のくぼみ・軸穴の深さ（14.2）が同じ、印刷用のノブです。

- 側面は縦溝 30 本（`KNOB_KNURL`）、上面に深さ 0.6 の指示線を別の色で埋めます。上面を下にして刷るので、色替えは最初の 3 層だけ
- 軸穴（`KNOB_GRIP`）：入口は Φ6.2 の丸、奥の 8mm だけ 18 山の星形（山の先の内径 5.6）。山がローレットに食い込んで回りません。付け根は 45°（上を下に刷っても宙に浮かない）
- 軸は 18 山なので 20° 刻みでしか付きません。ボリュームを左に回しきってから、指示線が最小の目盛りに一番近い向きで差します。ずれが気になれば `KNOB_ROT` で目盛りごと回します

## STL をきれいに保つ

水密でない・面積 0 の三角が出たことがあり、面がぴったり重なる作り方をやめました。

- 天板は「溝より上の外形＋差し込み」の 1 つの塊から削るだけにする（部品を 0.01 重ねてつなぐ・彫りを埋め戻すのをやめた）
- 爪の返しは裏より下まで伸ばし、最後に裏の面でまとめて切る（壁と爪が裏の 1 本の線で出会わないよう 0.1 ずらす）
- 最後に、印刷の向きで底を水平な面で 0.001 切り直す（傾いたまま作って戻すと底に点が残った）
- ノブの溝は、上面と同じ高さで切ると閉じた空洞になったので、溝だけ上へ 0.5 抜いて切る

今は top_plate・bottom_case・nano_clip とも水密で面積 0 の三角はありません。ツマミと fit_test には曲面のつなぎ目に面積 0 の三角が残りますが、刷って問題なかったのでそのままです。

## 組み立て

1. スライダー本体を天板の裏のくぼみに押し込んで爪で留める（ゆるければ M2 皿ネジを上から）
2. ボリュームを裏の丸いくぼみに入れ、表からナットで留める
3. Nano を押さえと一緒に底ケースへ入れる
4. 天板を底ケースに押し込んでスナップで閉じる（足りなければ M3×8 を底の座ぐりから四隅へ）
5. ツマミとノブを差す

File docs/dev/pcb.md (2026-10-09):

# 基板版（`pcb/`）

スライダー 5 本とノブを 1 枚の基板に載せ、Nano とはケーブル 3 本でつなぐ版です。配線を楽にするのが目的で、Nano・USB-C の位置・ファームウェア・アプリ・ピンの割り当ては配線版と同じです。作り方・部品・ケーブル・組み立て・注文は [pcb/README.md](../../pcb/README.md) にあります。ここには、決めたことと理由をまとめます。

状態：**実物で確認済み**（2026-10-08）。発注した基板を組み立て、6ch の値（端まで届く・隣がつられない）・LED 5 個・JH16K6 の端子と長穴・天板との合わせを確かめました。直す所はなかったので、データは `pcb-v0.1.0` のまま（Releases、プレリリースは外した）。ケースは、基板版の天板にノブの回り止めの穴が抜けていたので直しました（`case.py` で基板版だけ穴を外していた。ナットでパネルに留めるので、配線版と同じく要る）。

## 決めたこと

### Nano は載せず、ケーブルでつなぐ

「天板を閉じると基板の裏のソケットが Nano に刺さる」案は、基板の裏と Nano の上面のすき間が 5.4〜6.7mm しかなく、低いソケットとピンの切りそろえが要るのでやめました。Nano 側は 13 本ハンダ付けし、基板側は挿すだけにします。

### ケーブルは JST ZH の 3 本（電源 3 ピン・LED 6 ピン・信号 6 ピン）

秋月のコネクター付コード（ZH 相当、片側ハンダメッキ）をそのまま使えるからです。

- 秋月で ZH 相当のコードは 6P(H) 105719・6P 112604・3P 黒白赤 118272 だけ（同じ名前のコードでも、2P(A)・2P(E)・3P 黒橙白は PH、2P(B) は EH、7P と 6P 黄緑茶白黒赤は SH）。基板側の ZH 横向きは 2〜6 ピン（S?B-ZR-3.4）
- 分け方は「電源・信号・LED」。信号は Nano の A 側（A0〜A5 が連続）、LED は D 側の並びと同じ順
- JL（LED）と JA（信号）は Nano のすぐ左に縦に並べ、口を Nano へ向けます。端子の並びが Nano の端子と同じ前後の順なので、コードはまっすぐ右へ出て隣の Nano に付きます。JP（電源）はボリュームの近くで口は手前
- 1 番の向き：データシートの No.1（口から見て左、基板が下）を裏に付けた向きに直すと、「口が手前なら上から見て右端」「口が右なら奥の端」。コードの色と番号の対応は、Nano に付ける前にテスターで確かめます
- 経緯：PH 13 ピン（秋月に無い）→ XH 7＋6 → 秋月の ZH コード。配置も、口を奥向き（コードが奥の壁に当たる）→ 手前向き → 窮屈なので右へ広げる → Nano の横に縦に並べる今の形

### ノブは基板用のボリューム JH16K6B103L20KC-H13

秋月 117390。今の SH16K4 と同じ Supertech 16K シリーズの基板用（10kΩ B）です。

- **軸は基板と直角（上向き）**。端子は本体の前寄りから下へ出て、軸と平行に後ろへ伸び（取付面の 3.4〜13.4 後ろ、軸の中心から 13）、軸と直角な基板に刺さります。正面図で端子が端面（小さな四角）として描かれているのが決め手（最初は軸が基板と平行の横向きと読み違えていた）
- 本体は取付面から 9.3 とスライダー（7.0）より深いので、今と同じくナットでパネルに留め、基板の左奥を本体の形（円 R9＋端子の付け根の四角）に切り欠いて通します。端子の途中（幅約 2.9・厚さ約 0.4 の板）を基板の長穴（3.3×0.9、`POT_SLOT`）でハンダ付けします
- パネルの穴・回り止め・印刷のノブ・目盛り（300°）は配線版と同じものが使えます
- ほかの候補：秋月の 114937（基板用薄型）は軸のないダイヤル。Alps RK09L（縦）は取付面から基板まで 10mm・M9・D カット軸で合わない

### 部品はすべてスルーホール

JLCPCB には基板だけを頼み、部品は手でハンダ付けします（最初は 0805 の面実装を JLCPCB で実装する案だった）。

- 基板の表はスライダー本体と天板（すき間 0.5）でふさがるので、部品の本体は裏、ハンダは表にし、表に出る足とハンダの所は天板の裏を 3mm 彫って逃がします（足のまわり 1.5 の四角。`outline.json` の `reliefs`）
- 抵抗（1/4W・足の間隔 10.16・寝かせる）はスライダーの右のすき間（X＋7.5）。スライダー 5 だけ右に余地がないので左
- 摺動子の 0.1µF（秋月 104065）は同じすき間、ノブの 0.1µF は JA の右奥、5V の 10µF（秋月 100464、足の間隔 5mm）は JP の奥
- 裏の部品と底ケースの床のすき間は、いちばん狭い所で約 2mm

### LED の抵抗は 150Ω

LED をなるべく明るくするためです。5V − ピンの降下 約 0.4 − 1.8V ＝ 2.8V ÷ 150Ω ≈ 19mA（配線版の 330Ω の約 2.2 倍）。120Ω（約 23mA）・100Ω（約 28mA）は LED のデータシートの条件 20mA を超えるので、150Ω を下限にしました。5 個で約 95mA。

## 基板の作り方（`make_pcb.py`）

KiCad 10 の Python（pcbnew）で動かし、部品の配置・配線・ベタ・DRC・ガーバー・部品の一覧まで一度に作ります。

- 2 層 1.6mm。外形は L 字（X 13〜113・V 13.5〜90.5 ＋ 左奥 X 13〜78・V 90.5〜113.5）で、100×100 に収まります。Nano の真上は切り欠き
- 座標はケースと同じ X と、基板の上を測った V（パネルの傾き 3.3° の分だけ Y より長い。スライダーの中心 Y＝51 で V＝Y）
- **配線は自動（Freerouting 2.4.1）**：スクリプトは部品の配置と信号の割り当てだけを決め、Specctra DSN に書き出して Freerouting（`-mp 200`）で配線し、SES を読み込みます。手配線では 5V の線と帯の線の並びが交差して組めなかったためです
  - GND は DSN の網から消して自動配線させず、表裏のベタでつなぎます（表裏をつなぐビアは自分で置く）
  - 線の幅は全部 0.3（5V も。流れるのは 0.1A 程度）
  - 結果：DRC エラー 0・未接続 0、別に書いた回路との突き合わせで違い 0、銅の形を重ねた独自チェックでひとつながり・ショート 0
- KiCad に ZH 横向き（スルーホール）の部品形状が無いので、スクリプトで作ります（`zh_footprint`。1.5mm ピッチ、ピン Φ0.5、パッドは KiCad の ZH 上向きと同じ 1.03×1.73・穴 0.73）
- スルーホール部品の原点は 1 番の足なので、足 2 本の真ん中に動かして置きます（そのまま置くと半分ずれてスライダーと重なった）
- スライダーの端子の向き：4 本の列を手前にして上から見て左から 2・1・L・E（`MIRROR = False`、実物で確認済み）

### 落とし穴

- Freerouting 2.4.1 は Java 25 以上が要ります（Java 21 では `UnsupportedClassVersionError`）。winget の Temurin（MSI）は管理者の許可待ちで止まったので、zip 版の JRE 25 を `%LOCALAPPDATA%\deej-tab\tools` に展開して使います（`make_pcb.py` が探す）
- 外形に円弧の切り欠きを入れると、作ったばかりの基板のまま `ZONE_FILLER` で塗ると塗りが空になります。保存して読み込み直してから塗ります
- ZONE の `GetLayerName` は表裏とも `F.Cu` を返しますが、ファイルには正しい層が入ります（表示だけ）
- 裏のベタは斜めの線でいくつかに分かれますが、表のベタとビアでつながっているので問題ありません

## ケース（`case.py --pcb`）

`case/out/pcb/` に出します。引数なしは配線版で、出力は前とバイト単位で同じです（split の演算の順番を変えると三角形の分け方が変わるので、配線版は元の式のまま）。

- 天板の厚さ 8.5（パネル 2＋本体 7−すき間 0.5。本体 7.0±0.5 の短い個体でも基板を押さない）。スライダーの爪は無く、**M2×4 皿ネジ 10 本**で留めます。スナップと四隅の柱は自動で合います
- 基板の外形・コネクター・部品の位置は `pcb/outline.json`（`make_pcb.py` が書く）から読みます
- 干渉チェックに基板・JH16K6・裏の部品とケーブルの出口・表に出る足・裏に出る端子とハンダ（2.4）を入れています。スライダー 4 の端子のハンダと Nano のすき間は 2.5mm
- 配線版の底ケースと基板版の底ケースの違いは四隅の柱だけ（天板が `TOP_T_WIRED - TOP_T` = 1.8mm 薄いぶん高い。STL の差を取って確かめた）。なので配線版の底ケースは、柱に `spacer.stl`（同じ厚さ・柱と同じ外径 8.8・M3 の通し穴の輪）を載せれば使えます。柱とのすき間 `BOSS_GAP` はそのまま残ります。四隅のネジは天板へのかかりが 1.8 減るので M3×10

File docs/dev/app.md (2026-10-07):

# PC アプリ（`app/`）

公式 deej の代わりに使う、Python の常駐アプリです。COM ポートは 1 つのプロセスしか開けず、deej と拡張機能向けの中継サーバーを別々に動かせないため、1 つにまとめて作り直しました。`config.yaml` の形式は deej と互換です。

## 構成

| ファイル | 役割 |
|---|---|
| `deej_tab.py` | 本体。シリアル受信・音量の計算・WebSocket サーバー・トレイ・設定画面のウィンドウ |
| `ui.html` | 設定画面（本体が配信する 1 枚のページ） |
| `leds.py` | LED の光り方の計算（ファームウェアと同じ）・数値の範囲・端の位置の検証 |
| `winsys.py` | Windows の部品（ショートカット・最前面のアプリ・全画面の判定） |
| `macsys.py` | Mac の部品（[mac.md](mac.md)） |
| `appcatalog.py` | 割り当てに出すアプリの一覧とアイコン（Windows） |
| `obs.py` | OBS 連携（obs-websocket v5） |

スレッド：シリアルの受信と音量の変更（`serial_thread`）、WebSocket と HTTP（asyncio）、最前面のアプリの確認（0.5 秒ごと）、ショートカット。設定画面は別プロセス（`deej-tab.exe --settings`）で、閉じてもトレイの本体は残ります。

### 外とのつながり

| 窓口 | 相手 |
|---|---|
| `GET http://127.0.0.1:8765/` | 設定画面（`ui.html`）。`/favicon.ico`・`/icon.png`・`/appicon/xxx.exe`（同じオリジンからだけ） |
| `GET /health` | 拡張機能の起動確認（200 を返す） |
| WebSocket `/` | Chrome 拡張機能（[extension.md](extension.md)） |
| WebSocket `/ui` | 設定画面。Origin が `127.0.0.1:8765` の時だけ受け付ける |

## config.yaml

exe の隣に置きます（Mac の .app は `~/Library/Application Support/deej-tab/`）。なければ初期設定で作り、保存されると自動で読み直します。設定画面から保存するとコメントは消え、先頭に説明が入ります。

deej と同じキー：`slider_mapping`・`invert_sliders`・`com_port`・`baud_rate`・`noise_reduction`。割り当て先 `master`・`mic`・`system`・`deej.current`・`deej.unmapped`・`xxx.exe`、グループ指定（1 本に複数）も同じです。

deej-tab で足したキー：

| キー | 内容 |
|---|---|
| `enabled` | `false` で一時停止 |
| `slider_options` | スライダーごとの `invert`・`max_volume`・`unity_position`・`glide` |
| `glide` | 音量がスライダーについてくるまでの秒数（全体） |
| `restore_on_pause` | 一時停止・終了で音量を元に戻す |
| `pickup` | プロファイルを切り替えた時に音量を飛ばさない |
| `hotkeys` | 一時停止のショートカット |
| `profiles`・`active_profile` | プロファイル（2 つ以上ある時だけ書く） |
| `slider_calibration` | スライダーの端の位置（生の値） |
| `device_id` | つないだコントローラーの ID |
| `led_mode`・`led_params`・`led_presets` | LED |
| `obs` | OBS 連携 |
| `language` | `auto` / `ja` / `en` |
| `websocket_port` | 既定 8765 |

`noise_reduction` には deej にない `none`（1% ごと）があります。ファームウェアの平均で揺れが 0 になり、「強」（3.5%）だとゆっくり動かした時に音量が飛び飛びになったためです。

## 音量の計算

```
生の値 → 端の位置で 0〜1 に直す（calibrated）→ 1% に切り捨て → 反転
       → 揺れの抑え（noise_reduction のしきい値以上変わった時だけ）
       → スライダーの位置を音量に直す（slider_volume）
       → ついてくる（glide）→ 割り当て先にかける（apply）
```

- **いちばん上の音量**（`max_volume`、10〜400%）と **100% になる位置**（`unity_position`、5〜95%）：下は 0〜100%、上は 100%〜上限の 2 本の直線。省略すると比例（200% なら 50% の位置）。前後 2% は 100% ちょうどに吸い付きます
- **100% を超える分は Chrome のタブと OBS だけに効きます**。Windows のアプリ・全体・マイクは API の上限が 100% です
- **反転**：スライダーごとの `invert` は全体の `invert_sliders` と足し合わせません（個別の指定があればそれだけ。二重反転で元に戻ることはない）。全体と同じ値にしたら個別の指定は消し、「すべて反転」を切り替えると個別の指定は全部消えてそろいます
- **ついてくる**（`glide`）：スライダーを速く動かしても、音量が目標へ指数的に近づきます（最初は速く、近づくほどゆっくり。秒数で 95%）。30ms ごとに少しずつかけます（`glide_tick`）。一時停止中は止まり、プロファイルを切り替えた時は今の音量から始めます
- 設定画面の表示にも揺れの抑えをかけます（`shown_levels`）。音量とピックアップの判定は揺れの抑え前の値のままです

### 音量の掛かり方

- Windows のアプリの音量は、全体の音量に対する割合です
- タブの実際の音量 ＝ タブのスライダー × Chrome のアプリの音量 × 全体の音量
- スライダーの値は位置の絶対値です（ノブの中央 ＝ 50%。基準からの相対ではない）

## 割り当て先

| 割り当て先 | 動き |
|---|---|
| `master` / `mic` | 既定の出力・入力デバイスの音量 |
| `system` | システム音（通知音など） |
| `xxx.exe` | そのアプリの全セッション |
| `deej.current` | いちばん手前のウィンドウのアプリ。ほかのスライダーに割り当て済みのアプリと、`tab.N` を使っている時の Chrome には触らない（Chrome 全体を変えるとタブ用スライダーの上限まで変わるため）。Chrome が最前面なら、表示中のタブだけを拡張機能に変えさせる |
| `deej.game` | 最後に全画面だったアプリ（ウィンドウがモニター全体を覆い、タイトルバーなし・最大化でない）。ほかのウィンドウが前に来ても、終了するまで操作し続ける（Discord のオーバーレイや Alt+Tab のため） |
| `deej.unmapped` | どのスライダーにも割り当てていないアプリ全部 |
| `tab.N` | 拡張機能で番号 N を付けたタブ（1〜6） |
| `obs:ソース名` | OBS の音声ソース |

同じ割り当て先は 1 本のスライダーにしか置けません（ほかにあれば移動）。割り当て先と番号は `valid_target` で検証し、知らない操作にはエラーを返します。

## 一時停止と元に戻す

- `enabled: false` で一時停止。設定画面のヘッダーのスイッチ・トレイ・ショートカットで切り替えます。一時停止中はメーターだけ動き、音量は変えません。トレイと拡張機能のアイコンは灰色になります
- 再開すると、今のスライダーの位置で全部かけ直します
- **元に戻す**（`restore_on_pause`、初期設定オン）：一時停止・終了した時に、アプリ・マイク・OBS の音量を deej-tab が最初に変える前の値に戻します。最初に変える時に元の値を覚え（`_remember`）、戻したら忘れて、再開後にまた覚え直します
  - **全体の音量は戻さず、そのままにします**。起動した時の 100% に戻ると、止めた瞬間に急に大音量になるためです（Mac の出力も同じ）
  - Chrome のタブはこの設定に関係なく、一時停止で元の音量に戻ります（終了時も）

## プロファイル

割り当て一式（`slider_mapping`・`slider_options`）に名前を付けて切り替えます。上の `slider_mapping` が使用中のプロファイルの中身で、`profiles` に写しを持ちます（1 つしかなければ `profiles` は書かない＝deej と同じ形）。

- 設定画面の上・トレイのメニュー・プロファイルごとのショートカットで切り替えます
- **自動切り替え**（`auto_apps`）：そのアプリが最前面に来たら切り替え、そのアプリが**終了したら**元に戻します（後ろに回っただけでは戻さない）。自動で切り替わった後に手で戻したら、そのアプリがいったん前から外れるまで自動では切り替えません
- **ピックアップ**（`pickup`、初期設定オン）：切り替えた直後、各スライダーは割り当て先の今の音量の位置を通るまで効きません（差が 3% 以内になるか、またいだら効く）。設定画面は緑の点線、LED は点滅で知らせます。今の音量がわからない割り当て先（最前面のアプリなど）は待ちません

## コントローラーをつなぐ

- `com_port` を開き、5 秒何も届かなければ開き直します（スリープ復帰後に開いたまま止まることがあるため）
- つないで 2.5 秒 ID が来なければ `@I` で聞きます（開いてもリセットされない Nano のため）。初めての ID は `device_id` に覚えます
- `com_port` のポートが消えていたら、USB のシリアルポートだけ（Bluetooth は開くと待たされるので除く）を順に開いて 3.5 秒読み、同じ ID のものにつなぎ直して `com_port` を書き換え、設定画面にお知らせを出します。ID がわからなければ（古いファームウェア）、6 本分の値を送ってくる最初のポートにします
  - ほかの Arduino を何度もリセットしないよう、USB のポートの顔ぶれが変わった時だけ探します
  - ポートがあるのに開けない時（ほかのアプリが使っている）は探しません

### 受信の乱れと跳ねの記録

- つないだ直後の最初の値の行は使いません（途中から読んでいることがあるため）
- 本数の合わない行は、同じ本数が 2 行続くまで使いません。途中で切れた行を使うと値が 1 本ずつずれ、別のスライダーの値が一瞬入るためです
- 1 行で 25%（生の値 256）以上変わったスライダーは、割り当て先と前後の受信内容をログに残します。次の行で元に戻ったら「1 行だけ跳ねて戻りました」と残します（1 分に 20 件まで）。一瞬の爆音が、スライダーの値の跳ね（接触・受信の乱れ）から来ているかを見分けるためです

## スライダーの端の位置を合わせる

設定ページの「コントローラー」→「合わせる」で、各スライダーを上下の端まで動かして測ります。測っている間は音量を変えません。画面を閉じた時・切断した時も測るのをやめます。

- 保存すると `slider_calibration`（`0: [下端, 上端]`、生の値）に入ります。プロファイルを切り替えても変わりません
- 測った端から 8（`CAL_MARGIN`）だけ内側を 0% / 100% にします。0・1023 の近くまで届いていれば端そのものを使います
- 十分に動かしていないスライダー（範囲 300 未満・下端 > 400・上端 < 623、`leds.valid_calibration`）は前のままにします。端まで届いているスライダーは保存せず「合わせる必要はありません」と出します
- Nano は生の値を送り続けます（deej 互換）。アプリが `Config.calibrated()` で位置に直し、Nano にも `@C` で送って LED の判断（0 で消灯・位置で明るさ）に使わせます。操作したかどうかは生の値で見ます

## LED

`led_mode`：`off`（PC から指示しない）／`status`（状態を表示）／`meter`（音に合わせる）。形式は [hardware.md](hardware.md#pc-とのやりとり)。

- 状態：割り当て先が動いていない（`D`。タブ未割り当ての `tab.N` など）・0（`O`）・100% 超え（`B`）・ピックアップ待ち（`P`）
- 音に合わせる時は、割り当て先の音の大きさ（タブは拡張機能が測って送る）を 15 回/秒で送ります
- **光り方の設定**：設定ページの「LED の光り方」でプレビューを見ながら選びます。`led_params` には初期設定から変えたものだけ保存し、`@P` で Nano に送ります（`led_mode: off` でも送る）
  - 光り方ごとに数値を覚えます（`leds.STYLE_GROUPS`・`apply_change`）。切り替えると前に使っていた数値に戻り、初めての光り方は今の数値を引き継ぎます。`led_presets` に保存し、「初期設定に戻す」で消えます
- **プレビュー**：アプリの中の分身（`DeejTab.led_sim` ＝ `leds.LedSim`）が、Nano に送った行とスライダーの値を同じように受け取り、設定画面へ 20 回/秒で明るさを送ります。Nano がつながっていなければ PC なしの光り方を出します
- 書き込みが詰まる相手（受信を読まない古い仮スライダーなど）には、0.5 秒で諦めてその接続では LED の指示を送りません

## OBS 連携（`obs.py`）

- obs-websocket v5。割り当て先は `obs:ソース名` で、音声のあるソースだけ候補に出します
- 音量はタブと同じカーブ（100% までは 2 乗、超えた分はそのまま、OBS は 20 倍まで）
- パスワードは `config.yaml` に平文で保存します。パスワード違い（4009）はそう表示します

## ショートカット

`RegisterHotKey`（`winsys.py` の専用スレッド）。修飾キーなしは F13〜F24・Pause・ScrollLock だけ使えます。ほかのアプリが使っていれば設定画面に赤字で出します。

## 設定画面

- 本体が `http://127.0.0.1:8765/` で配信し、pywebview（Windows は Edge WebView2、Mac は WKWebView）の自前のウィンドウで開きます。pywebview がなければ Chrome / Edge のアプリウィンドウ（`--app`）で開きます
  - Chrome で開く時は専用のプロファイル（`%LOCALAPPDATA%\deej-tab\ui-profile`）を使います。普段の Chrome が起動中だと `--window-size` が無視されるためです
- ヘッダーで「ミキサー / 設定」の 2 ページに分かれます（`#settings` で設定ページ）。設定ページには、OBS につながらない・ショートカットを登録できない時に黄色い点が付きます
- タイトルバーは画面と同じ暗い色（DWM）。アイコンは `%LOCALAPPDATA%\deej-tab\icon.ico`
- 設定画面が開いていれば、トレイから開いても新しいウィンドウは出さず手前に出します。2 つ目の deej-tab を起動した時も、設定画面を開くだけで終わります。トレイから終了すると設定画面も閉じます
- メーターの塗りは実際の音量、つまみはスライダーの位置（目標）です。ついてくる途中はつまみが枠だけになり、塗りが追いかけます（`posOf` で音量 → 位置に直す）

### ウィンドウの大きさ

開いた最初の 1 回だけ、中身が切れないぎりぎりの大きさにして画面の中央に移します。

- 基準：名前は 2 行まで、「割り当てを追加」と見出しは 1 行、スクロールが出ない。幅は 1001 以上（狭いと 2 段になる）。幅 +40・高さ +16 の余裕を持たせる
- ミキサーのページで測ります。ページが必要な大きさを測り、自前のウィンドウなら `window.pywebview.api.fit`、Chrome なら `/ui` の `fit_window` で送ります。受けた側が Win32 でウィンドウを動かします（ページの `resizeTo` は最大化で開いた Chrome に効かなかった）
- ウィンドウの準備前に届いた頼みは取っておいて、出た時に合わせます（`SettingsApi._shown`）。ページ側は pywebview の窓口を最大 2 秒待ち、来なければ Chrome として頼みます
- 合わせた大きさは `%LOCALAPPDATA%\deej-tab\window.json` に覚え、次からは最初からその大きさで開きます

### 割り当ての追加（`appcatalog.py`）

音を出しているアプリ／起動中のアプリ（タスクバーに出るウィンドウ）／最近使ったアプリ（`%LOCALAPPDATA%\deej-tab\apps.json`）／インストール済み（スタートメニューのショートカット。Discord などの `Update.exe` 形式も解く）から選びます。検索・↑↓・Enter で選べ、自前のウィンドウなら「exe ファイルから選ぶ…」もあります。

- アイコンは exe から取り出して `/appicon/xxx.exe` で返します。複数スレッドで同時に取り出すとたまに失敗したので、1 つずつ順に行います

### 言語

- `language`：`auto`（Windows の表示言語。`GetUserDefaultUILanguage` が日本語なら ja、ほかは en）／`ja`／`en`。画面へは `options.language` と、auto を解いた `lang` を送ります
- `ui.html` は日本語で書き、英語の時は表示中の文字（テキスト・placeholder・title・aria-label・confirm）を `I18N_EN`（完全一致、空白は 1 つにまとめる）と `I18N_EN_RE`（数字や名前が入る文言）で置き換えます（`trText`・MutationObserver）。**文言を足したら `I18N_EN` にも英語を足します**。表にない文言は日本語のまま出ます
- 英語 → 日本語は元の文言を持っていないので読み直します。最後に使った言語は localStorage に覚えて、読み込み直後から使います
- 訳さないもの：ユーザーが付けたプロファイル名（初期の「標準」だけは Standard と出る）、COM ポートの名前、「日本語」
- タスクトレイは `TEXT_EN`・`tr()`。メニューは開くたびに作るので、言語を変えるとすぐ反映されます。ログは日本語のままです

## タスクトレイと自動起動

- pystray で常駐します。クリックで設定画面、右クリックで一時停止・プロファイル・自動起動・終了
- トレイのアイコンは、コントローラーがつながっていない間つまみが灰色になります。ツールチップに接続先と状態を出します
- 自動起動は HKCU の Run に登録します（`--tray` は設定画面を開かない）。exe を起動した時に Python 版のまま登録されていたら、exe に付け替えます

## アイコン

`deej_tab.py` の `app_icon()` で描きます（スライダー 3 本・赤いつまみ・LED の光）。exe（16〜256px）・トレイ・設定画面のファビコンとロゴ・拡張機能（`tools/make_ext_icons.py`）で同じ絵です。24px 以下は線を太くして飾りを省き、48px 以上だけ光・つや・指示線を付けます。

## exe（`build.py`）

- PyInstaller の onefile・windowed。`config.yaml` とログは exe の隣、`ui.html` は exe の中です
- バージョン情報（プロパティ・タスクマネージャーに「deej-tab 音量ミキサー」）。番号は `VERSION`
- 入れておかないといけないもの：`--hidden-import pystray._win32`、`--collect-submodules serial.urlhandler`（`socket://` の仮スライダー用）
- exe から自分（設定画面）を起動する時は `PYINSTALLER_RESET_ENVIRONMENT=1` を渡します。渡さないと親の展開フォルダを使い回し、親が先に終わると `_overlapped` がないと言って落ちます
- 起動時、パッケージが import できれば pip を飛ばします。WMI が固まると、pip が OS の情報を取るところで無言のまま止まるためです
- websockets のログは警告以上だけ残します（拡張機能の `/health` 確認のたびに記録されていたため）

## テスト（`app/tests/`）

| ファイル | 内容 |
|---|---|
| `test_core.py` | 設定・音量の計算などの単体 |
| `test_features.py` | 機能ごとの単体（ピックアップ・一時停止・端の位置・ID など） |
| `test_integration.py` | 空いているポートで本物のサーバーを立て、仮のシリアルから値を流して拡張機能・設定画面の通信を確かめる |
| `test_integration2.py` | 偽の OBS と、LED を受け取る仮の Nano を相手に通す |
| `test_mac.py` | 偽の補助プログラム（`fake_mac_helper.py`）で macsys を確かめる（Windows でも動く） |

テストは `DummyAudio` を使い、本物の音量には触りません。

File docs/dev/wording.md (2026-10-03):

# 画面の文言のルール

設定画面・トレイ・拡張機能に出す言葉は、初めて使う人が読んでわかる言葉にします。新しい文言もこれに合わせます。

## 言葉の選び方

- 本体は「コントローラー」と呼ぶ（「デバイス」「Nano」「実機」は使わない）。ファームウェアの書き込みなど技術的な説明だけ「Nano」
- 「既定」→「初期設定」、「〜した時」→「〜したとき」（時間・同時・起動時などの熟語はそのまま）、「繋ぐ」→「つなぐ」
- 専門用語を出さない

| 中身 | 画面の言葉 |
|---|---|
| 追従（glide） | 音量の変わり方（すぐ／なめらか／ゆっくり／とてもゆっくり） |
| ピックアップ | 音量を飛ばさない |
| スロット（拡張機能） | 番号 |
| ノイズ除去 | 揺れの抑え |
| 比例 | 自動 |

## 割り当て先の名前

| 割り当て先 | 画面の名前 |
|---|---|
| `master` / `system` / `mic` | 全体音量・システム音・マイク |
| `deej.current` | 今使っているアプリ |
| `deej.game` | ゲーム（全画面のアプリ） |
| `deej.unmapped` | そのほかのアプリ |
| `tab.N` | Chrome タブ N |
| `obs:…` | OBS の音声ソース |

## LED

- 設定の見出しは「LED で知らせること」（なし／状態／状態と音の大きさ）と「LED の光り方」（操作していないとき／起動したとき／操作したとき）
- 数値の名前は、選んでいる光り方に合わせて変える（例：往復する光 →「光の点の明るさ」「光の点が往復する速さ」。`ui.html` の `LED_MAIN`）
- 光り方の名前（`leds.py`）
  - 操作していないとき：点灯したまま・呼吸・流れる波・きらめき・鼓動・往復する光・スライダーの位置に合わせる
  - 起動したとき：左から右へ流れる・中央から広がる・全体がふわっと点く・左右に往復する
  - 操作したとき：明るく光る・波紋（端まで広がる）・スライダーの位置に合わせる

## 拡張機能

- 方式の名前は「タブの音をまとめて調整」（キャプチャ）と「ページ内の動画の音量を変える」

## 書き方

- 説明文（`<small>`）は文末に「。」を付けない。2 文以上は「。」で区切る
- 設定画面に文言を足したら、`ui.html` の `I18N_EN` に英語も足す（Mac 向けの言い換えは `MAC_TEXT`）

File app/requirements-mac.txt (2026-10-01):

# Mac 版 (build_mac.py) で使うもの。pywebview が pyobjc (Cocoa・WebKit など) も入れる
pyserial
websockets
pyyaml
psutil
pystray
pillow
pywebview
pyinstaller

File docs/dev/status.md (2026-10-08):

# 版の履歴と残っていること

## 版の履歴

### アプリ・ファームウェア

| 版 | 主な変更 |
|---|---|
| 1.3.2 | 一瞬の爆音の診断：スライダーの値が大きく跳ねたらログに残す。つないだ直後の行・本数の合わない行を使わない |
| 1.3.1 | 一時停止・終了で全体の音量を戻さない（止めた瞬間に急に大音量になるのを防ぐ） |
| 1.3.0 | 言語設定（日本語 / English）、Mac 版 |
| 1.2.0 | **最初の公開版**。プロファイル（自動切り替え・ショートカット）、音量を飛ばさない（ピックアップ）、一時停止で元に戻す、一時停止のショートカット、ゲーム（全画面のアプリ）、OBS 連携、LED 連携と光り方の設定、音量の変わり方、スライダーの端の位置合わせ、コントローラーの ID と別の USB の口に差した時の探し直し（ファームウェア 1.3） |
| 1.1.0 | 一時停止、スライダーごとの設定（反転・最大音量・100% になる位置）、アプリを一覧から選ぶ（非公開） |
| 1.0.0 | 最初の版（非公開） |

ファームウェアの zip はアプリの版の名前で作ります。中身は 1.2.0 から変わっていません。

### Chrome 拡張機能

| 版 | 主な変更 |
|---|---|
| 1.5.0 | 音が鳴ったタブを空いている番号へ自動で割り当てる（ポップアップでオン。方式 Y の時も、自動で割り当てたタブは方式 X で変える） |
| 1.4.1 | 方式 X（「今使っているアプリ」で Chrome のタブを下げる時も）で、YouTube の動画が始まる時などに一瞬元の音量で鳴るのを直す。下げたタブを再読み込みしたらかけ直す |
| 1.4.0 | ポップアップ・右クリックメニューを deej-tab の言語に合わせる |
| 1.3.1 | 最初の公開版（アプリ 1.2.0 と一緒に公開） |
| 1.3.0 | Alt+Shift+A で空いている番号へ順に割り当て |
| 1.2.0 | 番号のショートカット・右クリックメニュー・バッジ、割り当て済みの番号と音の大きさを deej-tab へ送る |
| 1.1.0 | 一時停止、100% 超えとリミッター |
| 1.0.0 | 最初の版 |

## 未確認

- **一瞬の爆音（経過観察中）**：動画を見ている時に、たまに一瞬大きな音が出る。方式 X・Y の両方で起きた（番号付きのタブ 2 でも）。再現しない
  - 方式 X で YouTube が音量を入れ直す時の一瞬は拡張機能 1.4.1 で直した。両方で起きるので、アプリから届く値（スライダーの値の跳ね・受信の乱れ）を疑い、1.3.2 で跳ねをログに残すようにした
  - 次に起きたら、その時刻の前後の `deej-tab.log` を見る：「跳ねました」「1 行だけ跳ねて戻りました」があればスライダー側（どのスライダーか・ノブか）、「シリアル切断」「拡張機能が切断」の直後なら、つなぎ直しの時の動き。何もなければ Chrome 側（キャプチャ・サイト）を疑う
- 拡張機能：deej-tab が起動していない時に、`chrome://extensions` にエラーが出なくなったか
- 拡張機能：方式 X のスクリプトが、拡張機能を消した時に音量を元に戻すか
- 方式 Y で、タブの音量が低いまま残り、ページの再読み込みで直ったことがあった（再現しないので保留）
- ケース：スライダーのレバーが本体の中心にあるか（ずれていれば `SLOT_OFFSET`）
- ケース：ツマミの爪の付き具合と穴のすき間 0.2、ノブの軸穴（`knob_fit_test.stl` で実物の軸に合わせる）
- Mac 版の残りは [mac.md](mac.md#未確認)

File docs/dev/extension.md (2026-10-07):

# Chrome 拡張機能（`extension/`）

タブに番号（1〜6）を付け、deej-tab から届いた音量をそのタブにかけます。Manifest V3、Chrome 116 以降。

| ファイル | 役割 |
|---|---|
| `background.js` | Service Worker。deej-tab との通信・割り当て・ショートカット・右クリックメニュー・バッジ |
| `offscreen.html` / `offscreen.js` | タブの音声をキャプチャしてゲインをかける（方式 Y） |
| `media-guard.js` | ページの中（MAIN world）で `<video>` / `<audio>` の `volume` を横取りする（方式 X） |
| `content-media.js` | 届いた音量を `media-guard.js` に渡す（方式 X） |
| `popup.*` | ツールバーのポップアップ（割り当ての一覧と今の音量） |
| `i18n.js`・`_locales/` | 文言 |

## 音量の変え方

| 方式 | 中身 | 向き不向き |
|---|---|---|
| **Y：タブの音をまとめて調整**（初期設定） | `tabCapture` でタブの音声を取り、Web Audio のゲインをかけて出す | 0 でしっかり無音。100% を超えられる。再読み込みしても続く |
| X：ページ内の動画の音量を変える | `<video>` / `<audio>` の `volume` を横取りして deej の音量にする | Web Audio や DOM の外の音には届かず、0 でもかすかに聞こえるサイトがある |

方式 Y を基本にし、X はポップアップで切り替えられるように残しています。

- 音量のカーブ：100% までは音量の 2 乗（`CURVE_POWER`。B カーブのスライダー前提）、超えた分はそのままの倍率（200% ＝ 2 倍）。方式 X は 1 まで
- 方式 Y は 100% を超える時だけリミッター（WaveShaper の柔らかい頭打ち、0.9 から）を通します。100% 以下では通さないので音は変わりません
- 方式 Y で別の番号へ移す時は、キャプチャを取り直さずに移します（offscreen の `capture-move`）
- 方式 X は `volume` の setter をページの中で置き換えます（`media-guard.js`）。サイトが音量を入れても実際の音量は deej の音量のままで、読み出しにはサイトが入れた値を返します（サイトの音量の表示・保存を変えない）。`play()` の前と、ページに足された要素にもかけます
  - 以前は `volumechange` を見てから上書きし直していたので、YouTube が動画・広告の始まりに音量を入れ直すたびに、一瞬元の音量で鳴っていました（スライダー 30% なら実際は 9% なので、一瞬約 11 倍になる）
  - 拡張機能側の `content-media.js` とは `document` の `__deej_tab_volume` イベントでやりとりします（`null` で元に戻す）
- 方式 X のスクリプトは、拡張機能が消えたり再読み込みされたりしたら（Port の切断で検知）、元の音量に戻して止まります

## 割り当て

- **Alt+Shift+A**：このタブを空いている一番小さい番号へ。押すたびに次の空きへ移り、最後の次は解除（ほかのタブが使っている番号は飛ばす）。空きがなければバッジに「満」
- **Alt+Shift+1・2**：番号を指定して割り当て、もう一度押すと解除。3〜6 は `chrome://extensions/shortcuts` で割り当て（Chrome が初期設定で付けられるショートカットは 4 つまで）
- **Alt+Shift+D**：ポップアップを開く
- ページの右クリック →「deej タブ音量」からも割り当て・解除できます
- バッジ：割り当てたタブは番号、deej-tab の設定にない番号は「?」、割り当てられないページ（`chrome://` やウェブストア）は「!」
- 割り当てと方式はメモリに持ち、変わった時だけ保存します。変更は 1 つずつ順に処理します（`serial`）。Service Worker の起動時に、閉じたタブ・終わったキャプチャの割り当てを外します（`reconcile`）

### 自動で割り当て

ポップアップの「音が鳴ったタブを自動で割り当てる」をオンにすると（初期設定はオフ。`storage.local` の `autoAssign`）、音が鳴り始めたタブを空いている一番小さい番号へ割り当てます。

- `tabs.onUpdated` の `audible` で知り、1 秒（`AUTO_DELAY_MS`）たっても鳴っていて、ミュートしていないタブだけ割り当てます（通知音などを拾わないため）
- 空きがなければ何もしません（割り当て済みのタブを追い出さない）。音が止まっても割り当ては残し、閉じた時に外します
- 方式 Y はタブごとにクリック・ショートカットが要り、自動ではキャプチャできません。そのため自動で割り当てたタブは、方式 Y の時も方式 X で変えます（`autoSlots`。`slotMethod()` がスロットごとの方式を返す）。ポップアップでは番号の横に「自動」と出します
  - そのタブを手で別の番号へ移すと、その時にキャプチャを始めて方式 Y になります。同じ番号のまま方式 Y にしたい時は、解除してから割り当て直します
  - `reconcile` と `capture-ended` は、方式 X で動いている番号を外しません（キャプチャがないのが普通なので）

## ポップアップ

- 配色は設定画面と同じ暗い色。番号は設定画面と同じ「タブ N」と出し、音量バーと値をリアルタイムに出します（Port で送る）
- ほかのタブに割り当て済みの番号は、タイトルのクリックでそのタブへ移動、× で解除、「入れ替え」でこのタブに替えます
- 一時停止中と 100% 超え（オレンジ）を表示します
- Chrome のエラーはわかる言葉にして出します（`background.js` の `explain`）

## deej-tab との通信

- deej-tab が起動していない時は、先に `GET /health` を確かめてから WebSocket を開きます（`chrome://extensions` に接続エラーが溜まらないように）
- deej-tab → 拡張機能：番号ごとの音量、`current`（表示中のタブ）、`enabled`（一時停止）、`lang`（言語）
- 拡張機能 → deej-tab：割り当て済みの番号（LED の「動いていない」表示に使う）、LED を音に合わせる時だけタブの音の大きさ（offscreen で測る）
- 一時停止中はタブを元の音量（ゲイン 1、方式 X は元の音量）に戻します

### 「今使っているアプリ」で Chrome が最前面の時

deej-tab から `current` が届いたら、最後に触ったウィンドウの表示中のタブを方式 X で変えます（方式 Y はタブごとにクリックが要り、自動ではキャプチャできないため）。

- 番号を割り当て済みのタブには触りません。あとで番号を割り当てたら、下げた分は戻します
- 下げたタブを再読み込みしたら、読み込みが終わった時に同じ音量をかけ直します（ページが変わるとスクリプトが消えて元の音量に戻るため）

## 文言

- ポップアップ・右クリックメニュー・アイコンの説明・エラーは `i18n.js`（`I18N.ja` / `I18N.en`、`t(key, ...)`）。deej-tab がつないだ時と言語を変えた時に送る `lang` を `storage.local` に覚えて使います。まだ届いていなければ Chrome の表示言語
- 拡張機能の名前とショートカットの説明は `_locales`（Chrome の表示言語。既定は en）
- `popup.html` は `data-i18n`（文字）・`data-i18n-html`（太字入り）・`data-i18n-aria`

## アイコン

`app_icon()` と同じ絵を `tools/make_ext_icons.py` で `extension/icons/` に書き出します。deej-tab が起動していない間は灰色のつまみになります。

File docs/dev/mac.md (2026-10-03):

# Mac 版

macOS 14.2 以降・Apple シリコンの Mac で動きます（アプリごとの音量に使う Core Audio の Process Tap が 14.2 から）。本体は Windows と同じ `deej_tab.py` で、OS ごとの部分だけを差し替えています。

- OS の分岐は `IS_MAC` / `sys.platform`。**Mac の変更で Windows 版の動作を変えない**
- `deej_tab.sysmod()` が `winsys` / `macsys` を返します

## Windows 版との対応

| 役割 | Windows | Mac |
|---|---|---|
| 音量 | `WindowsAudio`（pycaw） | `macsys.MacAudio` → 補助プログラム |
| アプリ一覧・アイコン | `appcatalog.AppCatalog` | `macsys.MacCatalog` |
| ショートカット・最前面のアプリ | `winsys.py` | `macsys.py` → 補助プログラム |
| 自動起動 | レジストリの Run | `~/Library/LaunchAgents/io.github.rikuyona.deej-tab.plist` |
| 設定画面 | pywebview（WebView2） | pywebview（WKWebView）。別プロセス `--settings` |
| 常駐 | タスクトレイ（pystray） | メニューバー（pystray darwin） |
| 設定・ログ（配布版） | exe の隣 | `~/Library/Application Support/deej-tab/` |

- アプリ名は `.app` の名前の小文字です（例 `discord.app`、`google chrome.app`）。Windows の `discord.exe` と同じ役割で、`EXE_RE` は両方を通します
- アプリの音量の倍率は音量の 2 乗です（`macsys.gain`。Chrome のタブと同じ感じ方にするため）
- `ui.html` は配信時に `<html lang="ja" data-platform="mac">` を埋め込みます。JS の `MAC_TEXT` / `MAC_PARTS` で Windows 向けの文言を Mac 向けに差し替え（英訳の後に置き換える）、`APP_EXT` で `.exe` / `.app` を切り替えます
- 初期設定は `discord.app` / `/dev/cu.usbserial`（なければ USB のポートを探す）
- ショートカットの表示は `⌃⌥⇧P` のように記号で出します

## 補助プログラム（`app/mac/deej-tab-helper.swift`）

本体（Python）が子プロセスとして起動し、標準入出力で 1 行 1 JSON をやりとりします。標準入力が閉じたら後片付けして終わります。

```
本体 → {"id": 1, "cmd": "set_gains", "gains": {"discord.app": 0.25}}
補助 → {"id": 1, "ok": true, ...}        失敗時 {"id": 1, "error": "..."}
補助 → {"event": "hotkey", "name": "pause"}
```

命令：`hello` / `get_volume`・`set_volume`（scope: output・input）/ `processes` / `set_gains` / `set_others`（deej.unmapped）/ `reset` / `meter` / `peaks` / `front` / `apps` / `names` / `icon` / `hotkeys`

### アプリごとの音量

- `CATapDescription(stereoMixdownOfProcesses:)` ＋ `muteBehavior = .mutedWhenTapped` の Tap と、出力デバイスを入れた非公開の集約デバイスを作ります。IOProc で Tap の入力（**最後の 2ch** を Tap とみなす）に倍率をかけ、出力の ch0/1 に書きます
- 倍率が 1 のアプリは Tap を作りません（何もしない）
- `Engine.reconcile()` が、プロセスの一覧と既定の出力デバイスの変化（リスナー＋2 秒ごと）に合わせて Tap を作り直します
- 子プロセス（Chrome Helper など）は `responsibility_get_pid_responsible_for_pid`（dlsym）と、実行ファイルのパスの一番外側の `.app` で親アプリにまとめます。Chrome は更新後に `…/code_sign_clone/…/Google Chrome.app.bundle` から動くので、`NSRunningApplication` の bundleURL を先に使います
- 自分と同じアプリ（deej-tab.app）のプロセスは対象外です
- 音を出していない常駐アプリは「再生中」に出しません（今出力しているものだけ）

### 録音の許可を待つ間

Tap の `AudioDeviceStart` は、録音の許可の返事を待つ間止まります。ほかの命令まで止まらないよう、`set_gains` / `set_others` / `reset` / `meter` はすぐ返事をして、Tap の作り直しは後で行います。`peaks` / `processes` は作り直しを待ちません（`tapsLock`）。作り直しに 0.5 秒以上かかったらログに出します。

### そのほか

- 音の大きさ（LED のメーター）：音量用の Tap があればそこから、なければ `.unmuted` の測るだけの Tap。全体は全体の Tap
- ショートカット：Carbon の `RegisterEventHotKey`（メインスレッド。`NSApplication.run()` で回す）
- 全画面の判定：最前面のアプリのいちばん手前のウィンドウ（`CGWindowListCopyWindowInfo`、layer 0）が画面の大きさ以上か
- API の書き方は [Mikser](https://github.com/erdmncdr/Mikser)（`AppTap.swift`）と [AudioCap](https://github.com/insidegui/AudioCap) を参考にしました

## アプリにする（`app/build_mac.py`）

- 補助プログラムを arm64 と x86_64 で作って lipo でまとめ、`deej-tab.app` と `release/deej-tab-<版>-mac.zip` を作ります（`--helper-only` で補助プログラムだけ）
- Info.plist に `LSUIElement`（メニューバーだけに出る）・`NSAudioCaptureUsageDescription`・`LSMinimumSystemVersion` を入れます
- 自己署名の条件を `identifier "io.github.rikuyona.deej-tab"` にしています。自己署名は中身のハッシュで同じアプリかを見るため、そのままだと作り直すたびに録音の許可が外れました

## 気をつけること

- **メニューバーは別スレッドから触ると落ちます**（`NSStatusItem setMenu:` で SIGTRAP）。`macsys.on_main`（`AppHelper.callAfter`）でメインスレッドから更新します
- ターミナル以外（エディタ・Claude Code など）の子プロセスとして動かすと、許可のダイアログが出ないまま Tap の音が 0 で届き、アプリの音が消えます。試す時は `.app` で
- 補助プログラムは自分と同じアプリの音を除くので、Claude Code から起動した `afplay` などは一覧に出ません（仕様どおり）

## 確認済み（実機）

テスト・Swift のコンパイル（警告のみ）・lipo、全体の音量、アプリごとの音量（Chrome の音が 100% / 0% で鳴る・消える）、`deej.current`・`deej.unmapped`（unmapped を下げても coreaudiod の CPU は +3% 程度）、設定画面とアプリ選択・アイコン、本物の Nano（`/dev/cu.usbserial-110` を自動で見つけた）・LED、Chrome 拡張機能（そのまま動く。Option+Shift+1 で割り当て）、メニューバー・一時停止・ログイン時の自動起動・ショートカット。

集約デバイスの入力は Tap の 2ch だけでした（確認した Mac の出力デバイスの場合）。

## 未確認

- 集約デバイスの入力で、出力デバイス自身の入力（USB オーディオインターフェースなど）が Tap より前に並ぶか（今は「最後の 2ch が Tap」としている）
- `mutedWhenTapped` の Tap で音が二重に出たり途切れたりしないか。倍率を 1 に戻して Tap を消す時のプツッという音
- Chrome の Helper が増えた時（新しいタブ）に、Tap の作り直しで音が途切れる時間
- Bluetooth ヘッドホンへの切り替えなど、既定の出力デバイスが変わった時に追従するか
- pystray（darwin）のアイコンの大きさ、メニューの「既定の項目」の扱い
- pywebview の `window.width` / `resize` が枠込みかどうか（`SettingsApi._fit_mac`）

## 対応していないこと（仕様）

- 「システム音」への割り当て（Mac に通知音だけの音量がないため。画面からも隠している）
- LED のメーターのマイクの音の大きさ（マイクの許可が要るため 0 を返す）
- 2 回目に deej-tab.app を開いた時に設定画面を出すこと（メニューバーから開く）
- アプリの音量の 100% 超え（Chrome のタブ・OBS は Windows と同じく超えられる）
- 一時停止・終了で、アプリの音量は横取りをやめるので 100% に戻ります（覚えた値には戻さない）

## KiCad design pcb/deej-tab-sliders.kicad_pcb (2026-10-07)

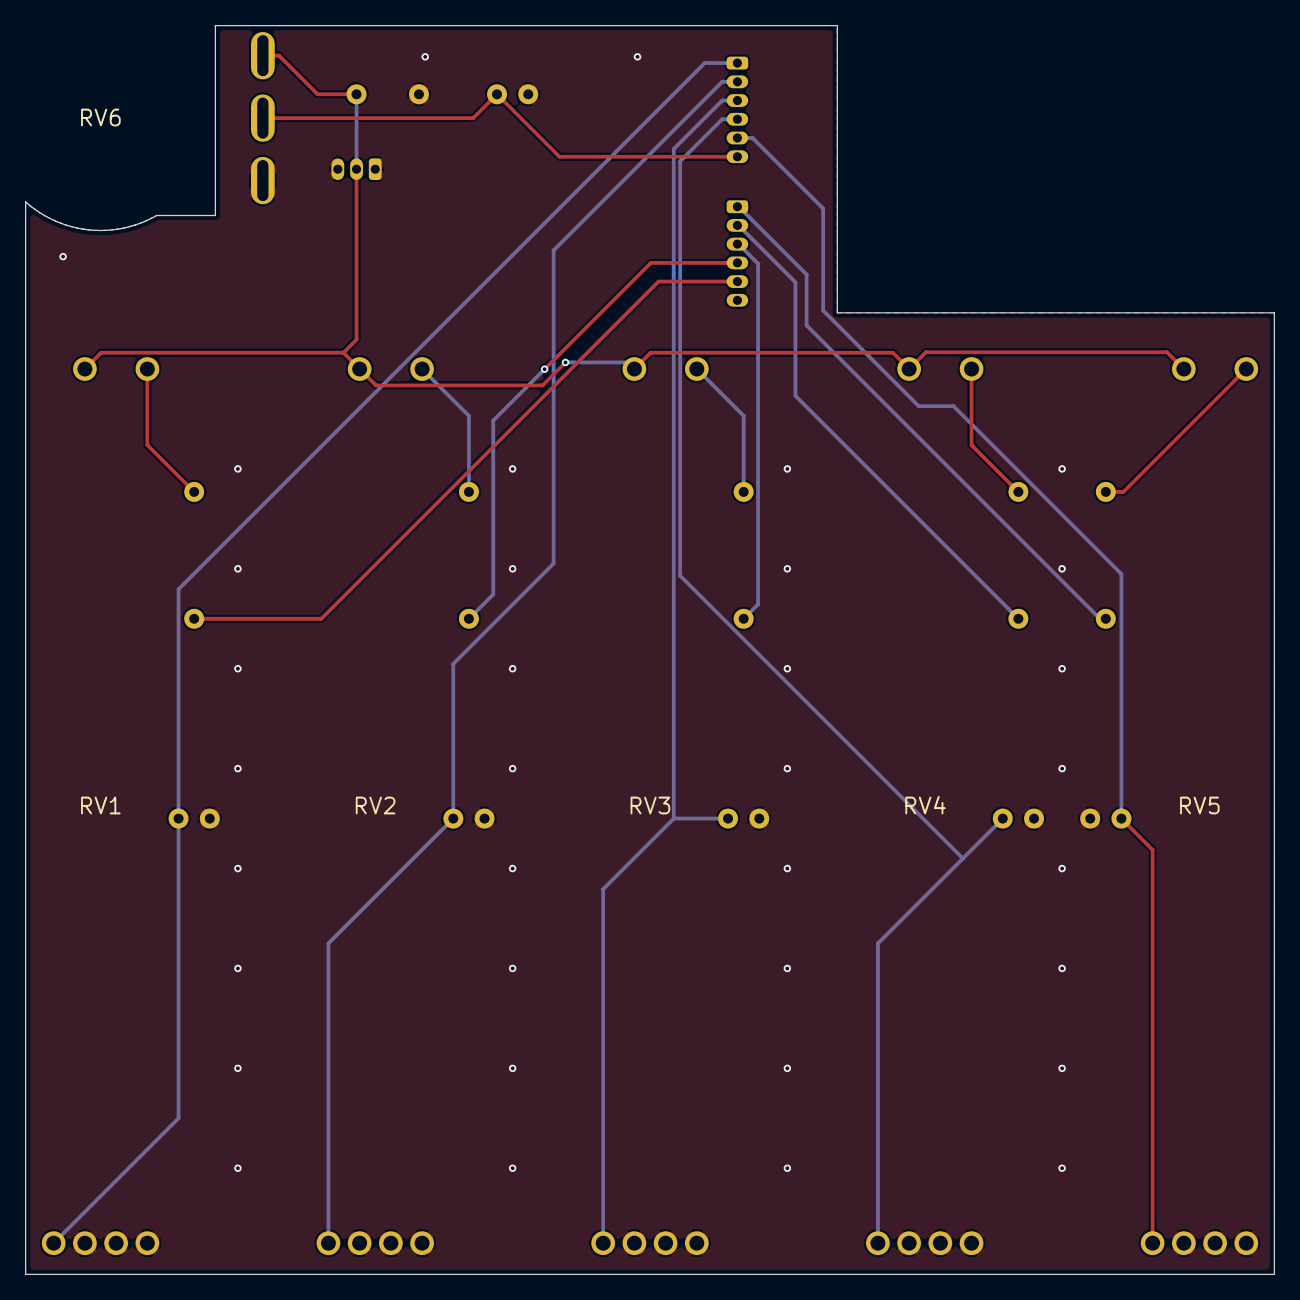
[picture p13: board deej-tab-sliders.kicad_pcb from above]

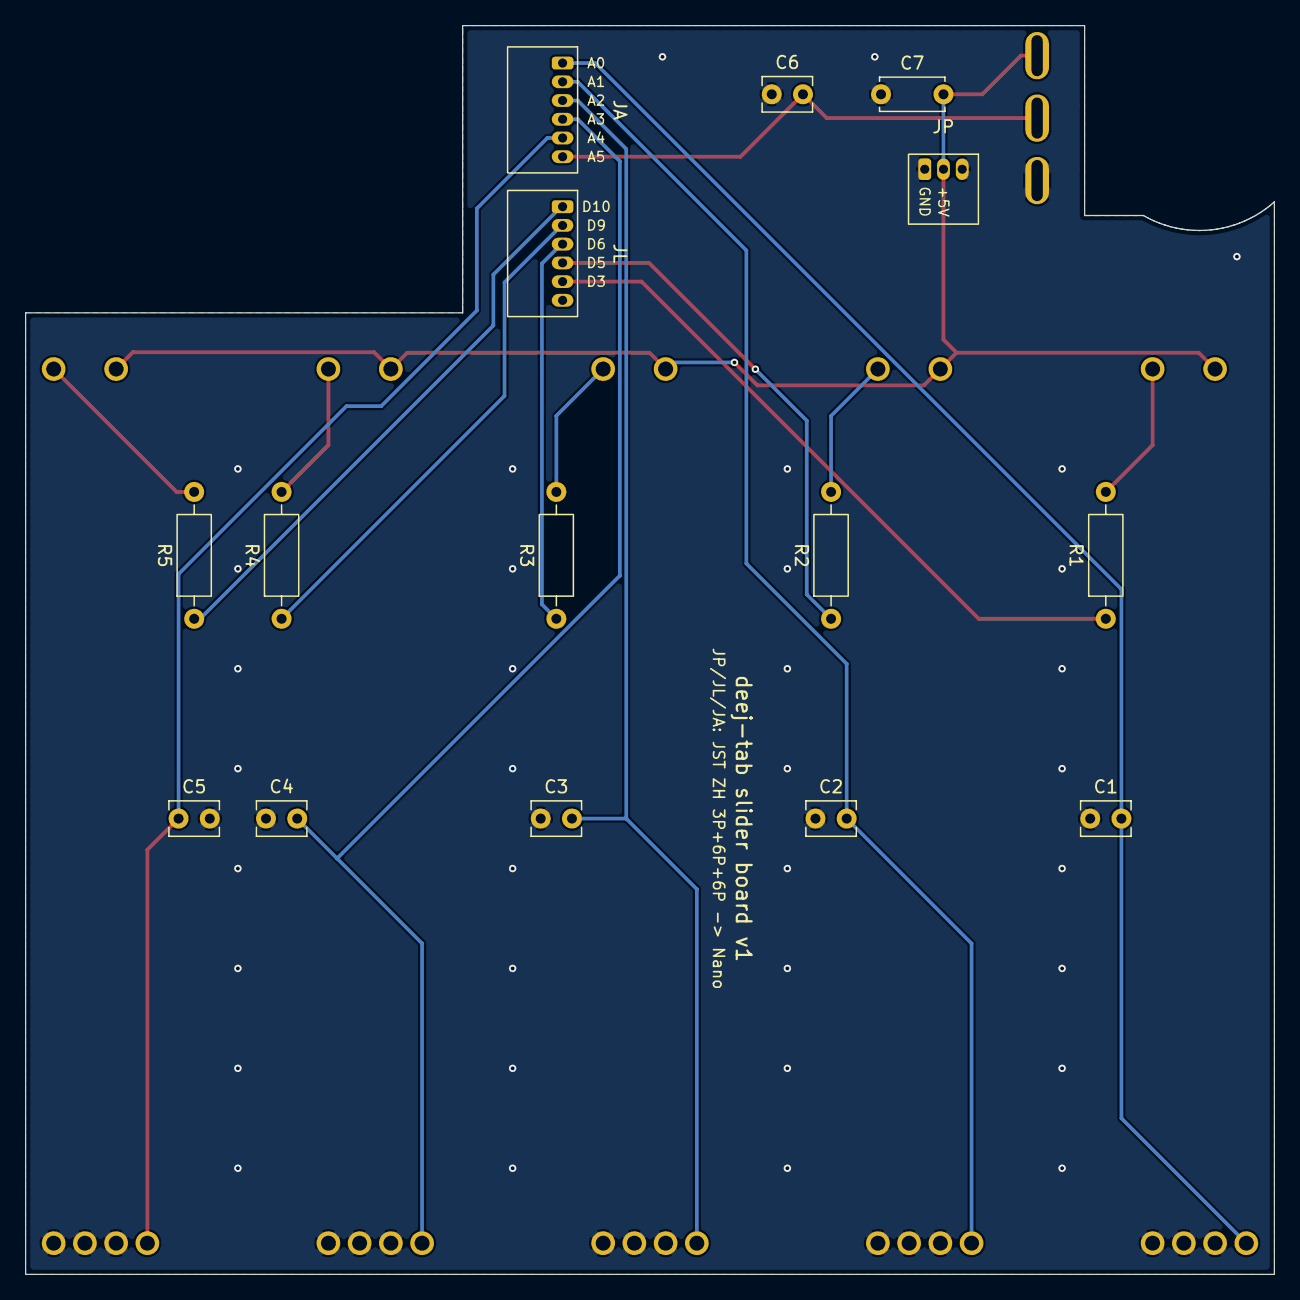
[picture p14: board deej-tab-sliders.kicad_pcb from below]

Board: 2 copper layers, 100.0 x 100.0 mm, 21 parts (12 on the bottom side), 18 nets.

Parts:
C1, C2, C3, C4, C5, C6: 100nF; C_Disc_D3.8mm_W2.6mm_P2.50mm
C7: 10uF; C_Disc_D5.0mm_W2.5mm_P5.00mm
JA: S6B-ZR; JST_ZH_S6B-ZR_Horizontal
JL: S6B-ZR; JST_ZH_S6B-ZR_Horizontal
JP: S3B-ZR; JST_ZH_S3B-ZR_Horizontal
R1, R2, R3, R4, R5: 150; R_Axial_DIN0207_L6.3mm_D2.5mm_P10.16mm_Horizontal
RV1, RV2, RV3, RV4, RV5: PTL60-15R0-103B2; Bourns_PTL60
RV6: JH16K6B103L20KC-H13; Supertech_JH16K6_H13_slots

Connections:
+5V: C7.2, JP.2, RV1.3, RV2.3, RV3.3, RV4.3, RV5.3, RV6.3
A0: C1.2, JA.1, RV1.2
A1: C2.2, JA.2, RV2.2
A2: C3.2, JA.3, RV3.2
A3: C4.2, JA.4, RV4.2
A4: C5.1, JA.5, RV5.2
A5: C6.2, JA.6, RV6.2
D3: JL.5, R1.1
D5: JL.4, R2.1
D6: JL.3, R3.1
D9: JL.2, R4.1
D10: JL.1, R5.1
GND: C1.1, C2.1, C3.1, C4.1, C5.2, C6.1, C7.1, JP.1, JP.3, RV1.1, RV1.E, RV1.L, RV2.1, RV2.E, RV2.L, RV3.1, RV3.E, RV3.L, RV4.1, RV4.E, RV4.L, RV5.1, RV5.E, RV5.L, RV6.1
LED1: R1.2, RV1.B
LED2: R2.2, RV2.B
LED3: R3.2, RV3.B
LED4: R4.2, RV4.B
LED5: R5.2, RV5.B

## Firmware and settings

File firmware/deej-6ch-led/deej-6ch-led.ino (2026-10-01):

// deej-6ch-led: スライダー 5 本 (LED 付き) + ノブ 1 つの deej 互換ファームウェア
//
// 送信 (Nano → PC): 公式 deej と同じ "v0|v1|v2|v3|v4|v5\n" (0〜1023)
//   起動した時と @I を受け取った時だけ "@ID|deej-6ch-led|1.3|A1B2C3D4" (このコントローラーの ID。公式 deej は読み飛ばす)。
//   CH340 には USB のシリアル番号がなく、別の USB の口に差すと COM 番号が変わるので、deej-tab はこの ID で探し直す
// 受信 (PC → Nano): LED の指示 (deej-tab 1.2 以降。app/leds.py と同じ取り決め)
//   @L|g|m0|m1|m2|m3|m4   g = 0 普通 / 1 一時停止
//                         m = N 普通 / O 消灯 / D 暗く / B 明滅 (100% 超え) / P 点滅 (ピックアップ待ち)
//   @V|l0|l1|l2|l3|l4     音の大きさ 0〜255 (LED を音に合わせて光らせる時)
//   @P|DIM=20|BRIGHT=255… 光り方の数値 (下の既定値と同じ名前。FADE_UP / FADE_DOWN は %)。
//                         変わったら 2 秒後に EEPROM に保存し、次に電源を入れた時もその光り方で動く
//   @B                    起動アニメをもう一度流す
//   @I                    ID をもう一度送る
//   @C|i|lo|hi            スライダー i (0〜5) の端の位置。生の値 lo を 0、hi を 1023 とみなす (deej-tab の「端の位置を合わせる」)。
//                         EEPROM に保存し、LED の判断 (0 で消灯・位置で明るさ) に使う。PC に送る値は生のまま
// PC から 3 秒何も来なければ、PC なしの光り方 (操作したら明るく約 2 秒、0 で消灯、5 分で減光) に戻る。
// 光り方の計算は app/leds.py の led_brightness() と同じにしてある (直す時は両方直す)。
//
// 配線: スライダー A0〜A4 (LED は D3 / D5 / D6 / D9 / D10、330Ω)、ノブ A5。D0 / D1 は USB シリアル

#include <EEPROM.h>

const char FW_NAME[] = "deej-6ch-led";
const char FW_VERSION[] = "1.3";

const int NUM_SLIDERS = 6;
const int NUM_LEDS = 5;
const int analogInputs[NUM_SLIDERS] = {A0, A1, A2, A3, A4, A5};
const int ledPins[NUM_LEDS] = {3, 5, 6, 9, 10};

// ---- 光り方の数値の既定値 (app/leds.py の PARAMS と同じ) ----
// deej-tab の設定画面で変えた数値は @P で届き、EEPROM に保存したものがこれより優先される
long DIM = 20;             // 普段の明るさ (0〜255)
long BRIGHT = 255;         // 操作した直後
long SLEEP = 4;            // 5 分操作がない時
long INACTIVE = 6;         // 割り当て先が動いていない時
long INACTIVE_TOUCH = 60;  // 割り当て先が動いていない時に操作した直後
long TOUCH_MS = 2000;      // 操作してから明るいままの時間
long SLEEP_MS = 300000;    // 5 分
long BREATH_MS = 1600;     // 100% 超えの明滅の周期
long BREATH_LOW = 60;      // 100% 超えの明滅の暗い側
long PAUSE_MS = 3000;      // 一時停止中のゆっくりした明滅の周期
long BLINK_MS = 250;       // ピックアップ待ちの点滅 (点灯・消灯それぞれ)
long BLINK_LEVEL = 160;    // ピックアップ待ちの点滅の明るさ
long SWEEP_MS = 120;       // 起動アニメの 1 こまの時間
long IDLE_STYLE = 0;       // 普段の光り方 0 一定 / 1 呼吸 / 2 流れる波 / 3 きらめき / 4 心拍 / 5 スキャナー / 6 位置で明るさ
long IDLE_MS = 4000;       // 普段の光り方の周期 (心拍はこの半分、きらめきは 1/4 ごとに光るか決める)
long IDLE_DEPTH = 180;     // 普段の光り方の強さ (DIM に上乗せする一番明るい所)
long TWINKLE_CHANCE = 20;  // きらめき: 1 こまで各 LED が光る確率 (%)
long BOOT_STYLE = 0;       // 起動アニメ 0 左から右へ / 1 中央から広がる / 2 全体がふわっと点く / 3 往復する
long TOUCH_STYLE = 0;      // 操作した時 0 明るく光る / 1 波紋 (端まで広がる) / 2 位置を表示
long RIPPLE_SPREAD = 60;   // 波紋: 1 つ離れるごとに残る明るさ (%)
long FADE_UP = 50;              // 明るくなる速さ (10ms ごとに差のこの % だけ近づく)
long FADE_DOWN = 15;            // 暗くなる速さ (%)
// ---- ここまで ----

// @P で受け取れる数値と範囲 (app/leds.py の PARAM_LIMITS と同じ)。
// EEPROM には この順で保存するので、新しい数値は必ず最後に足す
struct Param { const char *name; long *value; long lo; long hi; };
Param paramTable[] = {
  {"DIM", &DIM, 0, 255}, {"BRIGHT", &BRIGHT, 20, 255}, {"SLEEP", &SLEEP, 0, 255},
  {"INACTIVE", &INACTIVE, 0, 255}, {"INACTIVE_TOUCH", &INACTIVE_TOUCH, 0, 255},
  {"TOUCH_MS", &TOUCH_MS, 200, 6000}, {"SLEEP_MS", &SLEEP_MS, 10000, 3600000},
  {"BREATH_MS", &BREATH_MS, 300, 5000}, {"BREATH_LOW", &BREATH_LOW, 0, 255},
  {"PAUSE_MS", &PAUSE_MS, 500, 8000}, {"BLINK_MS", &BLINK_MS, 60, 1000}, {"BLINK_LEVEL", &BLINK_LEVEL, 10, 255},
  {"FADE_UP", &FADE_UP, 2, 100}, {"FADE_DOWN", &FADE_DOWN, 1, 100}, {"SWEEP_MS", &SWEEP_MS, 30, 500},
  {"IDLE_STYLE", &IDLE_STYLE, 0, 6}, {"IDLE_MS", &IDLE_MS, 800, 10000}, {"IDLE_DEPTH", &IDLE_DEPTH, 0, 255},
  {"TWINKLE_CHANCE", &TWINKLE_CHANCE, 0, 100}, {"BOOT_STYLE", &BOOT_STYLE, 0, 3}, {"TOUCH_STYLE", &TOUCH_STYLE, 0, 2},
  {"RIPPLE_SPREAD", &RIPPLE_SPREAD, 10, 95},
};
const int NUM_PARAMS = sizeof(paramTable) / sizeof(paramTable[0]);
const unsigned int EEPROM_MAGIC = 0xDE01;   // EEPROM に deej-tab の数値が入っている印
const unsigned long SAVE_DELAY_MS = 2000;   // 最後に数値が届いてから保存するまで (スライダーを動かしている間は書かない)
bool paramsDirty = false;            // 光り方の数値か端の位置が変わった (SAVE_DELAY_MS 後にまとめて保存)
unsigned long paramsChangedAt = 0;

// 端の位置 (キャリブレーション)。範囲は app/leds.py の valid_calibration と同じ
const int CAL_ADDR = 200;                   // EEPROM の場所 (光り方の数値の後ろ。数値が増えても重ならないよう離してある)
const unsigned int CAL_MAGIC = 0xCA01;
const int CAL_LO_MAX = 400, CAL_HI_MIN = 623, CAL_MIN_SPAN = 300;
int calLo[NUM_SLIDERS] = {0, 0, 0, 0, 0, 0};
int calHi[NUM_SLIDERS] = {1023, 1023, 1023, 1023, 1023, 1023};

// このコントローラーの ID。初めて起動した時に作って EEPROM に保存する (書き込み直しても消えない)
const int ID_ADDR = 240;
const unsigned int ID_MAGIC = 0x1D01;
unsigned long deviceId = 0;

const unsigned long PC_TIMEOUT_MS = 3000;
const unsigned long METER_TIMEOUT_MS = 300;
const int TOUCH_THRESHOLD = 8;      // これ以上動いたら「操作した」(ノイズで光らないように)
const int OVERSAMPLE = 8;           // 1 回の値を何回の読み取りの平均にするか (実機は触っていなくても ±6 揺れた)
const int HOLD = 3;                 // 平均してもこれ未満の変化は前の値のまま (端の 0 / 1023 は必ず出す)

int analogValues[NUM_SLIDERS];
int lastTouchValue[NUM_SLIDERS];
unsigned long touched[NUM_LEDS];
unsigned long idleSince = 0;
unsigned long bootStart = 0;
float shown[NUM_LEDS];              // 実際に出している明るさ (なめらかに変える)

// PC からの指示
bool pcSeen = false;
unsigned long pcTime = 0;
bool pcPaused = false;
char pcMode[NUM_LEDS] = {'N', 'N', 'N', 'N', 'N'};
bool meterSeen = false;
unsigned long meterTime = 0;
int meterLevel[NUM_LEDS];

char rx[64];
int rxLen = 0;

// ---- 光り方の計算 (app/leds.py と同じ。直す時は両方直す) ----

int clamp8(long v) { return v < 0 ? 0 : (v > 255 ? 255 : (int)v); }

// lo → hi → lo を period ミリ秒で繰り返す三角波
long triangle(unsigned long t, unsigned long period, long lo, long hi) {
  if (period < 2) period = 2;
  unsigned long x = t % period;
  unsigned long half = period / 2;
  unsigned long up = x < half ? x : period - x;   // 0 → half → 0
  return lo + (hi - lo) * (long)up / (long)half;
}

// きらめきの乱数 (32 ビットで回る)
unsigned long twinkleHash(unsigned long slot, int i) {
  unsigned long h = slot * 1103515245UL + (unsigned long)i * 2654435761UL + 12345UL;
  return (h >> 16) & 0x7FFF;
}

// 心拍: ドクン (強)、ドクン (弱) の 2 回
long heartbeat(unsigned long now, unsigned long period, long amp) {
  if (period < 400) period = 400;
  unsigned long x = now % period;
  if (x < 120) return amp * (long)(x < 60 ? x : 120 - x) / 60;
  if (x >= 200 && x < 320) {
    unsigned long y = x - 200;
    return amp * 6 / 10 * (long)(y < 60 ? y : 120 - y) / 60;
  }
  return 0;
}

// 普段の明るさ
int idleLevel(unsigned long now, long base, int i, int raw) {
  long d = IDLE_DEPTH;
  unsigned long period = IDLE_MS;
  if (IDLE_STYLE == 0 || base <= SLEEP) return (int)base;
  if (IDLE_STYLE == 1) return clamp8(triangle(now, period, base, base + d));
  if (IDLE_STYLE == 2) return clamp8(triangle(now + (unsigned long)i * period / (NUM_LEDS * 2), period, base, base + d));
  if (IDLE_STYLE == 3) {
    unsigned long slotMs = period / 4 < 50 ? 50 : period / 4;
    if ((long)(twinkleHash(now / slotMs, i) % 100) < TWINKLE_CHANCE) return clamp8(base + triangle(now, slotMs, 0, d));
    return (int)base;
  }
  if (IDLE_STYLE == 4) return clamp8(base + heartbeat(now, period / 2, d));
  if (IDLE_STYLE == 5) {
    long pos = triangle(now, period, 0, (NUM_LEDS - 1) * 100);
    long dist = labs((long)i * 100 - pos);
    return dist < 150 ? clamp8(base + d * (150 - dist) / 150) : (int)base;
  }
  if (IDLE_STYLE == 6) return clamp8((long)raw * (base + d) / 1023);
  return (int)base;
}

// 起動アニメの明るさ。終わっていたら -1
int bootLevel(int i, unsigned long t) {
  unsigned long step = SWEEP_MS < 10 ? 10 : SWEEP_MS;
  unsigned long k = t / step;
  if (BOOT_STYLE == 1) {                       // 中央から広がる
    if (k >= 3) return -1;
    return abs(i - 2) == (int)k ? (int)BRIGHT : (int)DIM;
  }
  if (BOOT_STYLE == 2) {                       // 全体がふわっと点く
    unsigned long total = step * 6, half = total / 2;
    if (t >= total) return -1;
    if (t < half) return (int)(BRIGHT * (long)t / (long)half);
    return (int)(BRIGHT - (BRIGHT - DIM) * (long)(t - half) / (long)(total - half));
  }
  if (BOOT_STYLE == 3) {                       // 往復する
    const int order[9] = {0, 1, 2, 3, 4, 3, 2, 1, 0};
    if (k >= 9) return -1;
    return order[k] == i ? (int)BRIGHT : (int)DIM;
  }
  if (k >= (unsigned long)NUM_LEDS) return -1; // 左から右へ流れる
  return (int)k == i ? (int)BRIGHT : (int)DIM;
}

// 操作した直後の明るさ (位置を表示なら、動かしている間は位置に合わせる)
int touchLevel(int raw) {
  if (TOUCH_STYLE == 2) {
    long v = (long)raw * BRIGHT / 1023;
    return (int)(v > DIM ? v : DIM);
  }
  return (int)BRIGHT;
}

// 端の位置を合わせた値 (0〜1023)。app/leds.py の calibrated() と同じ
int calibratedValue(int i) {
  int raw = analogValues[i];
  if (raw <= calLo[i]) return 0;
  if (raw >= calHi[i]) return 1023;
  return (int)((long)(raw - calLo[i]) * 1023 / (calHi[i] - calLo[i]));
}

int ledBrightness(int i, unsigned long now, int ripple) {
  int raw = calibratedValue(i);   // 明るさの判断は端の位置を合わせた値で (操作したかどうかは生の値で見る)
  bool sleeping = now - idleSince > (unsigned long)SLEEP_MS;
  int base = sleeping ? (int)SLEEP : idleLevel(now, DIM, i, raw);
  bool lit = now - touched[i] < (unsigned long)TOUCH_MS;
  if (!pcSeen || now - pcTime > PC_TIMEOUT_MS) {
    if (raw < 8) return 0;
    if (lit) return touchLevel(raw);
    return base > ripple ? base : ripple;
  }
  if (pcPaused) return (int)triangle(now, PAUSE_MS, 0, DIM);
  char m = pcMode[i];
  if (m == 'O') return 0;
  if (m == 'P') return ((now / BLINK_MS) % 2 == 0) ? (int)BLINK_LEVEL : 0;
  if (m == 'D') {   // 割り当て先が動いていなくても、隣を操作した時の波紋は出す
    int own = lit ? (int)INACTIVE_TOUCH : (int)INACTIVE;
    return ripple > own ? ripple : own;
  }
  if (lit) return touchLevel(raw);
  if (ripple > base) base = ripple;
  if (m == 'B') return (int)triangle(now, BREATH_MS, BREATH_LOW, BRIGHT);
  if (meterSeen && now - meterTime <= METER_TIMEOUT_MS) {
    return base + (int)((long)meterLevel[i] * (BRIGHT - base) / 255);
  }
  return base;
}

// ---- 光り方の数値 (@P と EEPROM) ----

// EEPROM: [0] 印 (2 バイト) [2] 数値の個数 [3〜] 数値 (long) を paramTable の順に
void loadParams() {
  unsigned int magic;
  EEPROM.get(0, magic);
  if (magic != EEPROM_MAGIC) return;
  int count = EEPROM.read(2);
  for (int i = 0; i < NUM_PARAMS && i < count; i++) {
    long v;
    EEPROM.get(3 + i * 4, v);
    if (v >= paramTable[i].lo && v <= paramTable[i].hi) *paramTable[i].value = v;
  }
}

// EEPROM.put は変わったバイトだけ書くので、同じ数値なら書き込み回数は増えない
void saveParams() {
  EEPROM.put(0, EEPROM_MAGIC);
  EEPROM.update(2, (byte)NUM_PARAMS);
  for (int i = 0; i < NUM_PARAMS; i++) EEPROM.put(3 + i * 4, *paramTable[i].value);
}

bool validCalibration(long lo, long hi) {
  return lo >= 0 && lo <= CAL_LO_MAX && hi >= CAL_HI_MIN && hi <= 1023 && hi - lo >= CAL_MIN_SPAN;
}

// EEPROM: [CAL_ADDR] 印 (2 バイト) [+2〜] スライダーごとに 下端・上端 (int)
void loadCalibration() {
  unsigned int magic;
  EEPROM.get(CAL_ADDR, magic);
  if (magic != CAL_MAGIC) return;
  for (int i = 0; i < NUM_SLIDERS; i++) {
    int lo, hi;
    EEPROM.get(CAL_ADDR + 2 + i * 4, lo);
    EEPROM.get(CAL_ADDR + 4 + i * 4, hi);
    if (validCalibration(lo, hi)) { calLo[i] = lo; calHi[i] = hi; }
  }
}

void saveCalibration() {
  EEPROM.put(CAL_ADDR, CAL_MAGIC);
  for (int i = 0; i < NUM_SLIDERS; i++) {
    EEPROM.put(CAL_ADDR + 2 + i * 4, calLo[i]);
    EEPROM.put(CAL_ADDR + 4 + i * 4, calHi[i]);
  }
}

// ID を読む。まだなければ作る (アナログ入力の揺れと時間を混ぜる。暗号用ではなく、手持ちのコントローラーどうしが重ならなければよい)
void loadOrMakeId() {
  unsigned int magic;
  EEPROM.get(ID_ADDR, magic);
  if (magic == ID_MAGIC) {
    EEPROM.get(ID_ADDR + 2, deviceId);
    if (deviceId != 0 && deviceId != 0xFFFFFFFFUL) return;
  }
  unsigned long h = 2166136261UL;
  for (int k = 0; k < 64; k++) {
    for (int i = 0; i < NUM_SLIDERS; i++) {
      h = (h ^ (unsigned long)analogRead(analogInputs[i])) * 16777619UL;
    }
    h = (h ^ micros()) * 16777619UL;
    delayMicroseconds((h & 0x3F) + 10);
  }
  if (h == 0 || h == 0xFFFFFFFFUL) h = 0x13579BDFUL;
  deviceId = h;
  EEPROM.put(ID_ADDR + 2, deviceId);
  EEPROM.put(ID_ADDR, ID_MAGIC);
}

void sendId() {
  char buf[48];
  snprintf(buf, sizeof(buf), "@ID|%s|%s|%08lX", FW_NAME, FW_VERSION, deviceId);
  Serial.println(buf);
}

// "2|12|1008" (番号|下端|上端) を読む。範囲外は捨てる
void handleCalibration(char *s) {
  char *p1 = strchr(s, '|');
  if (!p1) return;
  char *p2 = strchr(p1 + 1, '|');
  if (!p2) return;
  int i = atoi(s);
  long lo = atol(p1 + 1), hi = atol(p2 + 1);
  if (i < 0 || i >= NUM_SLIDERS || !validCalibration(lo, hi)) return;
  if (calLo[i] != lo || calHi[i] != hi) {
    calLo[i] = (int)lo;
    calHi[i] = (int)hi;
    paramsDirty = true;
    paramsChangedAt = millis();
  }
}

// "DIM=20|BRIGHT=255" を読む。知らない名前は無視、範囲外は範囲に収める
void handleParams(char *s) {
  while (*s) {
    char *end = strchr(s, '|');
    if (end) *end = 0;
    char *eq = strchr(s, '=');
    if (eq) {
      *eq = 0;
      long v = atol(eq + 1);
      for (int i = 0; i < NUM_PARAMS; i++) {
        if (strcmp(s, paramTable[i].name) != 0) continue;
        if (v < paramTable[i].lo) v = paramTable[i].lo;
        if (v > paramTable[i].hi) v = paramTable[i].hi;
        if (*paramTable[i].value != v) {
          *paramTable[i].value = v;
          paramsDirty = true;
          paramsChangedAt = millis();
        }
        break;
      }
    }
    if (!end) break;
    s = end + 1;
  }
}

// "@L|0|N|N|D|B|O" / "@V|12|0|255|3|0" / "@P|DIM=20|…" / "@C|0|12|1008" / "@B" を読む。形が違う行は捨てる
void handleLine(char *line) {
  if (line[0] != '@') return;
  if (line[1] == 'B' && line[2] == 0) {
    bootStart = millis();
    return;
  }
  if (line[1] == 'I' && line[2] == 0) {
    sendId();
    return;
  }
  if (line[1] == 'P' && line[2] == '|') {
    handleParams(line + 3);
    return;
  }
  if (line[1] == 'C' && line[2] == '|') {
    handleCalibration(line + 3);
    return;
  }
  if (line[2] != '|') return;
  char kind = line[1];
  char *fields[1 + NUM_LEDS];
  int n = 0;
  char *p = line + 3;
  fields[n++] = p;
  while (*p && n < 1 + NUM_LEDS) {
    if (*p == '|') { *p = 0; fields[n++] = p + 1; }
    p++;
  }
  unsigned long now = millis();
  if (kind == 'L' && n == 1 + NUM_LEDS) {
    for (int i = 0; i < NUM_LEDS; i++) {
      char m = fields[1 + i][0];
      if (m != 'N' && m != 'O' && m != 'D' && m != 'B' && m != 'P') return;
    }
    pcPaused = fields[0][0] == '1';
    for (int i = 0; i < NUM_LEDS; i++) pcMode[i] = fields[1 + i][0];
    pcSeen = true;
    pcTime = now;
  } else if (kind == 'V' && n == NUM_LEDS) {
    for (int i = 0; i < NUM_LEDS; i++) {
      int v = atoi(fields[i]);
      meterLevel[i] = v < 0 ? 0 : (v > 255 ? 255 : v);
    }
    meterSeen = true;
    meterTime = now;
  }
}

void readSerial() {
  while (Serial.available()) {
    char c = Serial.read();
    if (c == '\n' || c == '\r') {
      if (rxLen > 0) {
        rx[rxLen] = 0;
        handleLine(rx);
      }
      rxLen = 0;
    } else if (rxLen < (int)sizeof(rx) - 1) {
      rx[rxLen++] = c;
    } else {
      rxLen = 0;   // 長すぎる行は捨てる
    }
  }
}

int readAveraged(int pin) {
  analogRead(pin);   // ピンを切り替えた直後の 1 回は前のピンの電圧が残るので捨てる
  long sum = 0;
  for (int k = 0; k < OVERSAMPLE; k++) sum += analogRead(pin);
  return (int)((sum + OVERSAMPLE / 2) / OVERSAMPLE);
}

void updateSliderValues() {
  unsigned long now = millis();
  for (int i = 0; i < NUM_SLIDERS; i++) {
    int v = readAveraged(analogInputs[i]);
    if (abs(v - analogValues[i]) >= HOLD || v == 0 || v == 1023) analogValues[i] = v;
    if (abs(analogValues[i] - lastTouchValue[i]) >= TOUCH_THRESHOLD) {
      lastTouchValue[i] = analogValues[i];
      if (i < NUM_LEDS) touched[i] = now;
      idleSince = now;
    }
  }
}

void sendSliderValues() {
  String builtString = String("");
  for (int i = 0; i < NUM_SLIDERS; i++) {
    builtString += String((int)analogValues[i]);
    if (i < NUM_SLIDERS - 1) builtString += String("|");
  }
  Serial.println(builtString);
}

void updateLeds() {
  unsigned long now = millis();
  // 起動アニメの間はそのまま出す
  if (bootLevel(0, now - bootStart) >= 0) {
    for (int i = 0; i < NUM_LEDS; i++) {
      shown[i] = bootLevel(i, now - bootStart);
      analogWrite(ledPins[i], (int)shown[i]);
    }
    return;
  }
  // 波紋: 操作した LED から端まで全部に広げる (1 つ離れるごとに RIPPLE_SPREAD % ずつ弱く)。
  // 割り当て先が動いていない (D) LED を操作した時は、その LED と同じ INACTIVE_TOUCH から広げる (真ん中より隣が明るくならないように)
  bool pcLive = pcSeen && now - pcTime <= PC_TIMEOUT_MS;
  int ripple[NUM_LEDS] = {0, 0, 0, 0, 0};
  if (TOUCH_STYLE == 1) {
    for (int j = 0; j < NUM_LEDS; j++) {
      if (now - touched[j] >= (unsigned long)TOUCH_MS) continue;
      long peak = (pcLive && pcMode[j] == 'D') ? INACTIVE_TOUCH : BRIGHT;
      for (int i = 0; i < NUM_LEDS; i++) {
        if (i == j) continue;
        long v = peak;
        for (int d = abs(i - j); d > 0; d--) v = v * RIPPLE_SPREAD / 100;
        if (v > ripple[i]) ripple[i] = (int)v;
      }
    }
  }
  for (int i = 0; i < NUM_LEDS; i++) {
    int target = ledBrightness(i, now, ripple[i]);
    // 明るくする時は速く、暗くする時はゆっくり (点滅・一時停止の明滅はそのまま出す)
    float k = (target > shown[i] ? FADE_UP : FADE_DOWN) / 100.0;
    if (pcLive && (pcMode[i] == 'P' || pcPaused)) k = 1.0;
    shown[i] += (target - shown[i]) * k;
    analogWrite(ledPins[i], (int)(shown[i] + 0.5));
  }
}

void setup() {
  loadParams();
  loadCalibration();
  for (int i = 0; i < NUM_SLIDERS; i++) pinMode(analogInputs[i], INPUT);
  for (int i = 0; i < NUM_LEDS; i++) {
    pinMode(ledPins[i], OUTPUT);
    shown[i] = DIM;
  }
  Serial.begin(9600);
  loadOrMakeId();
  sendId();
  for (int i = 0; i < NUM_SLIDERS; i++) {
    analogValues[i] = readAveraged(analogInputs[i]);
    lastTouchValue[i] = analogValues[i];
  }
  unsigned long now = millis();
  idleSince = now;
  bootStart = now;   // 起動アニメは updateLeds の中で時間に合わせて出す (その間も値は送る)
  for (int i = 0; i < NUM_LEDS; i++) touched[i] = now - (unsigned long)TOUCH_MS;
}

void loop() {
  readSerial();
  updateSliderValues();
  sendSliderValues();
  updateLeds();
  if (paramsDirty && millis() - paramsChangedAt >= SAVE_DELAY_MS) {
    saveParams();
    saveCalibration();
    paramsDirty = false;
  }
  delay(10);
}

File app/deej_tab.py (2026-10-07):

"""deej-tab: deej 互換のPCアプリ + Chromeタブ音量用 WebSocket 配信

- Arduino からのシリアル行 "v0|v1|...|vN" (0〜1023) を読み取る
- config.yaml の slider_mapping に従って Windows / Mac の音量を変える (deej 互換)
- 割り当て先が "tab.N" のスライダーは、WebSocket で Chrome 拡張へ送る
- 設定画面 (ui.html) を http://127.0.0.1:8765/ で配信し、/ui の WebSocket で割り当てを変更する
- タスクトレイ (Mac はメニューバー) に常駐する (pystray)

Windows 固有の部品は winsys.py・appcatalog.py、Mac 固有の部品は macsys.py (と補助プログラム mac/)
"""

import asyncio
import collections
import copy
import ctypes
import json
import logging
import math
import os
import re
import subprocess
import sys
import threading
import time
import urllib.parse
from http import HTTPStatus

import serial
import websockets
import yaml
from websockets.datastructures import Headers
from websockets.http11 import Response

import leds

log = logging.getLogger("deej-tab")

VERSION = "1.3.2"

LINE_RE = re.compile(r"^\d{1,4}(\|\d{1,4})*$")
# コントローラーの ID の行 (ファームウェア deej-6ch-led 1.3 以降): @ID|名前|版|8 桁の 16 進
ID_RE = re.compile(r"^@ID\|([\w.-]{1,24})\|([\w.]{1,8})\|([0-9A-F]{8})$")
NOISE_THRESHOLDS = {"none": 0.005, "low": 0.015, "default": 0.025, "high": 0.035}   # none は 1% ごと (位置は 1% 刻みなので 0.01 だと誤差で止まる)
SPECIAL_TARGETS = {"master", "mic", "system", "deej.current", "deej.unmapped", "deej.game"}
TAB_RE = re.compile(r"^tab\.([1-9]\d*)$")
# アプリの名前: Windows は exe 名、Mac は .app の名前 (どちらも小文字)
EXE_RE = re.compile(r"^[\w .\-()+&']+\.(exe|app)$")
IS_MAC = sys.platform == "darwin"
CHROME_APPS = ("chrome.exe", "google chrome.app")   # タブの音量を拡張機能で変えるブラウザ
OBS_RE = re.compile(r"^obs:([^\x00-\x1f|]{1,100})$")
PROFILE_NAME_RE = re.compile(r"^[^\x00-\x1f]{1,24}$")
DEFAULT_PROFILE = "標準"
LED_MODES = ("off", "status", "meter")

PICKUP_TOL = 0.03            # ピックアップ: 今の音量との差がこれ以内になったら効き始める
WATCH_INTERVAL = 0.5         # 秒。最前面のアプリ (ゲームの追従・プロファイルの自動切り替え) の確認間隔
LED_INTERVAL = 0.1           # 秒。LED の状態を計算する間隔 (変わった時か LED_HEARTBEAT ごとに送る)
LED_HEARTBEAT = 1.0          # 秒。Nano は 3 秒 PC から何も来ないと PC なしの光り方に戻る
METER_INTERVAL = 1 / 15      # 秒。LED を音に合わせる時に音の大きさを送る間隔
LED_PARAMS_RESEND = 5.0      # 秒。光り方の数値を送り直す間隔 (Nano は接続した時にリセットされ、起動中の行を取りこぼすので)
METER_FLOOR_DB = -48.0       # これより小さい音は LED を光らせない
TAB_METER_STALE = 0.5        # 秒。拡張機能からの音の大きさがこれより古ければ 0 とみなす

# スライダーごとの音量の上限 (%) と「100% にする位置」(スライダーの何 % の所か)
MAX_VOLUME_RANGE = (10, 400)
UNITY_RANGE = (5, 95)
GLIDE_RANGE = (0.0, 10.0)    # 秒。音量がスライダーについてくるまでの時間 (0 = すぐ)
GLIDE_INTERVAL = 0.03        # 秒。ゆっくりついてくる時に音量を変える間隔
GLIDE_DONE = 0.005           # 目標との差がこれ以下になったら目標に合わせて終わる
UNITY_SNAP = 0.02            # 100% の位置の前後これだけは 100% ちょうどに吸い付かせる
CAL_MARGIN = 8               # 端の位置を合わせる時、測った端からこれだけ内側を 0% / 100% にする (端で揺れても確実に届くように)

SESSION_REFRESH_MIN = 5.0    # 秒。これより短い間隔ではセッション一覧を取り直さない
SESSION_REFRESH_MAX = 45.0   # 秒。これより古い一覧はスライダー操作時に取り直す
CONFIG_POLL = 2.0            # 秒。config.yaml の更新確認間隔
SERIAL_STALE = 5.0           # 秒。これだけ何も届かなければ繋ぎ直す (スリープ復帰後の固まり対策)
JUMP_LOG = 256              # 生の値。1 行でこれ以上変わったスライダーをログに残す (一瞬の爆音の診断用。25%)
JUMP_LOG_MAX = 20            # 1 分にログに残す跳ねの数の上限 (速く動かし続けた時にログがあふれないように)
ID_ASK_AFTER = 2.5           # 秒。つないでからこれだけ ID が来なければ @I で聞く (Nano は開くとリセットされ、起動時に送る)
PROBE_TIME = 3.5             # 秒。コントローラーを探す時に 1 つのポートを読む時間
TRAY_CHECK = 5.0             # 秒。トレイアイコンが消えていないかの確認間隔
KEEPALIVE = 20.0             # 秒。拡張機能の Service Worker を維持するための ping 間隔
UI_LEVEL_INTERVAL = 0.05     # 秒。設定画面へスライダー値を送る間隔
UI_REFRESH = 5.0             # 秒。設定画面へアプリ一覧・COMポート一覧を送り直す間隔
CHANNELS = 6                 # 設定画面に出すスライダー数 (A0〜A5)

# exe 化 (PyInstaller) した時は、config.yaml とログは exe の隣、ui.html は exe の中
FROZEN = getattr(sys, "frozen", False)
APP_DIR = os.path.dirname(sys.executable) if FROZEN else os.path.dirname(os.path.abspath(__file__))
if IS_MAC and FROZEN:
    # .app の中には書き込まない (署名が壊れる・更新で消える) ので、config.yaml とログはユーザーのフォルダ
    APP_DIR = os.path.join(os.path.expanduser("~/Library/Application Support"), "deej-tab")
    os.makedirs(APP_DIR, exist_ok=True)
RES_DIR = getattr(sys, "_MEIPASS", APP_DIR)
RUN_KEY = r"Software\Microsoft\Windows\CurrentVersion\Run"
RUN_NAME = "deej-tab"
CONFIG_ARG = None   # 起動時に config.yaml の場所を指定されたとき (設定画面のプロセスにも渡す)
# 設定画面用の Chrome プロファイルと、前回合わせたウィンドウの大きさ
UI_DATA_DIR = (os.path.join(os.path.expanduser("~/Library/Application Support"), "deej-tab") if IS_MAC
               else os.path.join(os.environ.get("LOCALAPPDATA") or APP_DIR, "deej-tab"))
UI_PROFILE_DIR = os.path.join(UI_DATA_DIR, "ui-profile")
WINDOW_FILE = os.path.join(UI_DATA_DIR, "window.json")
SETTINGS_LOCK = os.path.join(UI_DATA_DIR, "settings.lock")   # Mac: 設定画面を 1 枚だけにする
DEFAULT_WINDOW = (1045, 1010)   # 論理ピクセル (150% なら実際は 1.5 倍)。window.json がない時だけ使う

LANGUAGES = ("auto", "ja", "en")
# タスクトレイなど Python 側で出す文言の英語 (設定画面の英語は ui.html の I18N_EN)
TEXT_EN = {
    "設定を開く": "Open settings",
    "一時停止 (スライダーで音量を変えない)": "Pause (sliders don't change the volume)",
    "プロファイル": "Profile",
    "Windows の起動時に自動で起動": "Start with Windows",
    "ログイン時に自動で起動": "Start at login",
    "終了": "Quit",
    "deej-tab - 一時停止中 (スライダーで音量は変わりません)": "deej-tab - Paused (sliders don't change the volume)",
    "deej-tab - {port} に接続中": "deej-tab - Connected to {port}",
    "deej-tab - デバイス未接続 ({port})": "deej-tab - Controller not connected ({port})",
}


def system_language():
    """Windows / Mac の表示言語が日本語なら ja、それ以外は en"""
    if IS_MAC:
        import macsys
        lang = macsys.system_language()
        if lang:
            return lang
    if sys.platform == "win32":
        try:
            return "ja" if (ctypes.windll.kernel32.GetUserDefaultUILanguage() & 0x3FF) == 0x11 else "en"
        except Exception:
            pass
    import locale
    return "ja" if (locale.getlocale()[0] or "").lower().startswith(("ja", "japanese")) else "en"


def resolve_language(language):
    """設定の language (auto / ja / en) から、実際に使う言語 (ja / en)"""
    return system_language() if language == "auto" else language


def sysmod():
    """ホットキー・最前面のアプリの部品 (Windows: winsys / Mac: macsys)"""
    if IS_MAC:
        import macsys
        return macsys
    import winsys
    return winsys


def tr(text, lang, **kw):
    """Python 側の文言を lang の言語にする。kw は {name} の差し込み"""
    return (TEXT_EN.get(text, text) if lang == "en" else text).format(**kw)


DEFAULT_CONFIG = """slider_mapping:
  0: tab.1
  1: tab.2
  2: tab.3
  3: discord.exe
  4: deej.current
  5: master
enabled: true
invert_sliders: false
com_port: COM3
baud_rate: 9600
noise_reduction: default
websocket_port: 8765
"""
if IS_MAC:
    # Mac のポート名は差した口ごとに変わるので仮の名前にしておく (見つからなければ USB のポートを探す)
    DEFAULT_CONFIG = (DEFAULT_CONFIG.replace("discord.exe", "discord.app")
                      .replace("com_port: COM3", "com_port: /dev/cu.usbserial"))
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

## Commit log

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2026-10-01 仮スライダーから LED 実験を削除
    光り方の調整は設定画面の「LED の光り方」で行うため、仮スライダーの
    LED 実験の欄（状態の手動選択・数値のスライダー・書き出し）を削除。
    LED の表示は deej-tab から届いた指示どおりに光らせるだけにした。
    書き出し専用だった leds.firmware_constants とそのテストも削除。
2026-10-01 ケースの STL は MakerWorld で配布する
    README のケースの節を MakerWorld への案内に変え、release.py は
    STL の zip を作らないようにした。
2026-10-01 印刷用の回転ノブと軸穴のはめ合いテストを追加
    knob_shape() を ABS-28 の見た目のモデルから印刷用に置き換えた。外形・
    底のくぼみ・軸穴の深さは ABS-28 と同じ。軸穴は奥 8mm に 18 山の星形を
    立てて 6mm ローレット軸に食い込ませる。指示線は乳白の別パーツで 2 色。
    knob_body / knob_line / knob_fit_test (山の内径 5.5/5.6/5.7) を出力する。
2026-10-01 README の部品表を直す (LED 抵抗の範囲・Nano の種類・ネジ)
    LED 用抵抗を 330Ω 固定から 180Ω〜1kΩ にした。PTL60 の赤色 LED は
    データシートで IF = 20mA・VF = 1.8V (標準) なので、5V では 160Ω 以上が
    必要。あわせて、ケースは USB-C 版の Nano 互換ボード専用であること、
    回転ボリュームの条件、スライダーを留める M2 皿ネジを部品表に足した。
2026-10-01 README に使い方を画像付きで追加
    設定画面の GIF・ミキサー・割り当ての追加・スライダーごとの設定・
    設定ページ・端の位置合わせ・拡張機能のポップアップの画像を docs/images に
    置き、使い方 (割り当て先の一覧、スライダーごとの設定、Chrome のタブの
    割り当て方と 2 つの方式、プロファイル、一時停止、設定) を書いた。
    画像は音量を変えないデモ用の構成で撮影した。
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2026-10-01 言語設定を追加 (日本語 / English) し、1.3.0 / 拡張機能 1.4.0 にする
    - アプリ: config.yaml の language (auto / ja / en)。auto は Windows の表示言語。
    設定画面の「言語 / Language」で切り替え。設定画面は表示中の文字を対訳表
    (I18N_EN と I18N_EN_RE) で英語に置き換える。タスクトレイのメニューと
    ツールチップも英語にする
    - 拡張機能: 文言を i18n.js にまとめ、ポップアップ・右クリックメニュー・
    アイコンの説明・エラーを deej-tab の言語に合わせる (アプリから lang を送る)。
    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
2026-10-01 Mac 版を追加 (試験中・Mac での実機確認はまだ)
    - アプリごとの音量は Core Audio の Process Tap を使う Swift の補助プログラム (app/mac/deej-tab-helper.swift)
    - macsys.py: 補助プログラムとのやりとり・音量・アプリ一覧・ショートカット・自動起動 (LaunchAgent)
    - deej_tab.py / ui.html: OS ごとの分岐と Mac 向けの文言 (.app の名前・メニューバー・Command など)
    - build_mac.py: deej-tab.app と配布用 zip を作る
    - tests/test_mac.py: 偽の補助プログラムで macsys をテスト
    - Mac版_引き継ぎ.md: Mac での確認作業の引き継ぎ
2026-10-01 Mac 版を Mac の実機で確認して直す
    - メニューバーの更新をメインスレッドで行う (別スレッドから触ると落ちていた)
    - Chrome のアプリ名を起動中のアプリの .app から取る (更新後の Chrome は一時フォルダの複製から動く)
    - 音量・音の大きさの設定はすぐ返事し、Tap の作り直しを待たない (録音の許可待ちで全部止まっていた)
    - .app の署名の条件をバンドル ID にして、作り直しても録音の許可が残るようにする
    - Mac の初期設定を discord.app / /dev/cu.usbserial にする
    - 「再生中」は今音を出しているアプリだけにする
    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
2026-10-03 スライダー基板 (基板版) を追加し、ケースに --pcb を足す
    配線を楽にするため、スライダー 5 本とノブを 1 枚の基板に載せ、Nano とは
    JST ZH のコード 3 本 (電源 3 ピン・LED 6 ピン・信号 6 ピン) でつなぐ版。
    Nano・USB-C の位置、ファームウェア、アプリは配線版のまま使える。
    - pcb/make_pcb.py: KiCad 10 の Python で部品の配置と信号を決め、
    Freerouting で自動配線し、DRC・ガーバー・部品表まで作る
    - ノブは秋月の JH16K6 (SH16K4 の基板用)。本体は基板の切り欠きを通し、
    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
    [deej-tab-sliders.kicad_pcb]
2026-10-03 一時停止・終了で全体の音量を戻さないようにし、1.3.1 にする
    restore_on_pause で、全体の音量 (master) を deej-tab が最初に変える前の値
    (起動時の 100% など) に戻していたため、一時停止・終了した瞬間に急に
    大音量になることがあった。全体の音量は今のままにし、アプリ・マイク・OBS
    だけ元に戻す (Mac の出力も同じ)。設定画面・README の説明も合わせる。
2026-10-03 開発資料を docs/dev/ にまとめ、README を使う人向けにする
    - 引き継ぎメモ (手元) と Mac版_引き継ぎ.md を、テーマ別の設計資料に書き直して
    docs/dev/ に置く (hardware / app / extension / mac / case / wording / status)
    - docs/dev/README.md を開発ガイドにし、README の「ソースから動かす」と
    Mac のビルド手順を移す。README からはリンクだけにする
    - Claude Code 向けの約束ごとを .claude/CLAUDE.md に置く (トップに出さない)
2026-10-04 拡張機能: 方式 X で一瞬元の音量で鳴るのを直し、1.4.1 にする
    YouTube は動画・広告が始まるたびに video.volume を入れ直す。これまでは
    volumechange を見てから上書きし直していたので、その間の一瞬だけ元の音量
    (たいてい 100%) で鳴っていた (「今使っているアプリ」で Chrome のタブを
    下げている時など)。
    - media-guard.js をページの中 (MAIN world) に入れ、volume の setter を
    置き換える。サイトが入れた値は覚えて読み出しに返し、実際の音量は deej
    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
2026-10-07 拡張機能: 音が鳴ったタブを自動で割り当てられるようにし、1.5.0 にする
    ポップアップの「音が鳴ったタブを自動で割り当てる」をオンにすると、
    1 秒以上鳴り続けたタブを空いている一番小さい番号へ割り当てる。
    空きがなければ何もせず、音が止まっても割り当ては残す。
    方式 Y は自動ではキャプチャできないので、自動で割り当てたタブは方式 X で変える。
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2026-10-07 スライダーの値の跳ねをログに残し、受信の乱れた行を使わないようにして 1.3.2 にする
    動画を見ている時にたまに一瞬大きな音が出る件の診断。
    1 行で 25% 以上変わったスライダーと、次の行で戻ったかをログに残す。
    つないだ直後の最初の行と、本数の合わない行 (同じ本数が 2 行続くまで) は使わない。
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2026-10-09 基板版の天板にノブの回り止めの穴を開け、Nano の押さえをきつめにする
    - 基板版の天板だけ回り止めの逃げを外していた。JH16K6 もナットでパネルに留めるので、配線版と同じ穴を開ける
    - Nano の押さえのくぼみと止めのすき間を片側 0.2 → 0.05 (横・前後)。止めの板が刷り上がりで約 0.2 薄く出てスカスカだった。きつければ削って合わせる
2026-10-12 ファームウェア: 操作したスライダーの LED で、触っていないスライダーが揺れるのを直し、1.3.3 にする
    LED の電流で GND が少し浮くので、続けて読むと PWM の点いた瞬間・消えた瞬間の
    どちらを拾うかで値が ±3 ほど揺れていた (基板版で LED の抵抗を 150Ω にしてから目立った)。
    8 回の読み取りを PWM の 1 周期 (2040µs) に散らし、15 秒の往復でほかの値が一度も変わらなくなった。
    - tools/crosstalk_test.py: LED を光らせた時と消した時で、つられを測る
    - tools/release.py --firmware: ファームウェアだけの zip を FW_VERSION の名前で作る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
2026-10-12 アプリ 1.4.0: 初めての PC でのセットアップを楽にする (インストーラー・ファームウェアの書き込み・見つからない時の案内)
    お父さんの PC でつまずいた所 (zip の展開と置き場所・Windows の警告・コントローラーにつながらない
    (原因は互換品の Nano の CH340 ドライバ)・Arduino IDE での書き込み) を直す。
    - Windows のインストーラー (Inno Setup 6、installer/deej-tab.iss)。%LOCALAPPDATA%\Programs に入れ、
    スタートメニュー・自動起動・拡張機能のフォルダ・アンインストール。上書き前は --quit で止める
    - 設定画面からファームウェアを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
